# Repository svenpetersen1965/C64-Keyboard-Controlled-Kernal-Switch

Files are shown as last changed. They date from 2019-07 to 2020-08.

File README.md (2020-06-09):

# C64-Keyboard-Controlled-Kernal-Switch
This is a Kernal Switch for the Commodore C64, which does not requires any case modifications. The Kernal is selected by holing RESTORE and pushing a number key. 

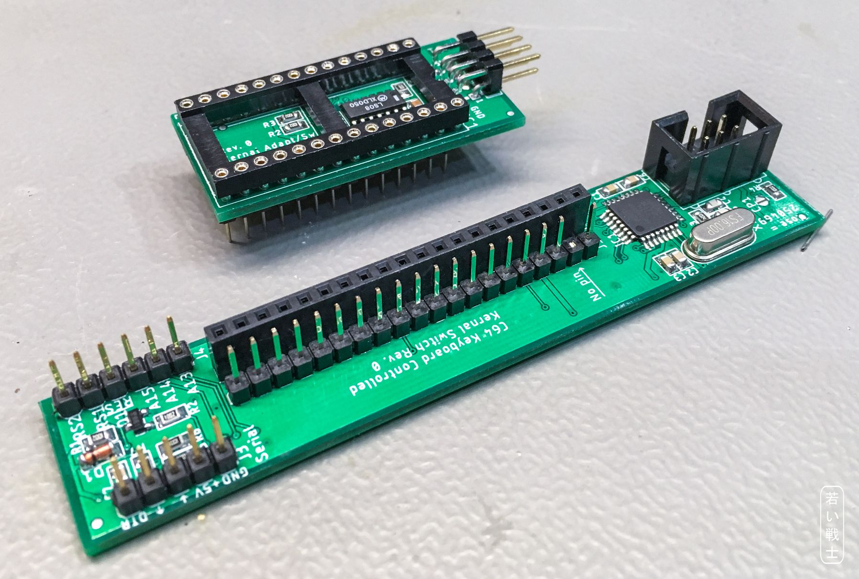
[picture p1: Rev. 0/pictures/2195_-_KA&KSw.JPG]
Kernal Switch and Kernal Adaptor


Jusrt holding RESTORE for several seconds will reset the C64. The index of selected Kernal is stored non-volatile, so the last selection will be executed after a power on.

Find some info on the required cable making <a href="http://tech.guitarsite.de/cable_making.html">on my website</a>

Watch the introduction on youtube: https://youtu.be/pfJxfMYcyzs

The Kernal Switch works in conjuctuion with a Kernal Adaptor:

https://github.com/svenpetersen1965/C64-Kernal-Adaptor-Switch-short-board- for ASSY 250469 Mainboards

https://github.com/svenpetersen1965/C64-Kernal-Adapter-Switch-Long-Board for all other Mainboards

I want to thank MindFlareRetro (https://www.youtube.com/channel/UCBbbiZC2YodIp2Pi-lywG-A/featured) for reviewing my documentation.

# Known Issue
Solved:

Some games/software require an EXROM-Reset, because they change the reset and/or NMI vector. Then the reset does not jump, where it should jump. It even seems, that the problem is persistent even after a power off. Don't panic... your C64 will function again, later. It seems, those games leave some traces in RAM, which have to get lost after being powered off for a while. 

This can be solved by also holding EXROM low while the reset. One of the two reserved IO pins in the pin header can serve to assert EXROM. The software will be changed and the result will be tested.

The problem stated above is some kind of copy protection and is described in detail here: http://tech.guitarsite.de/cbm80.html 

## Software Rev. 0.1
This software fixes the issue described above. An aditional connection is required. J4, Pin 5 (RS1) has to be connected to the EXROM signal (Expansion port, Pin 9, which can easily be accessed inside the C64) via a 220R resistor. The documentation has been updated.

## Software Rev. 0.2
This software makes use of the last free GPIO pin on J4 (Pin 6, "RS2" on Rev. 0 or "RESIO" on Rev. 1). A LED, that is connected there, will be on most of the time. When holding the RESTORE key and the time (about 3 seconds) is elapsed to initiate a "normal" reset, the LED switch off for a short time. Holding RESTORE for 5 seconds will initiate an EXROM reset. The LED signal should help to release the RESTOR key in time for a normal reset.

Board Rev. 1 already provides a current limiting resistor for an LED (R9). A value of 330R is suitable for a red, green or yellow LED, 50R is suitable for a blue LED.

Board Rev. 0 does not provide this resistor. Here, a resistor has to be installed in the LED cable. DO NOT try to connect an LED without a resistor!!! Theis can damage the LED and also the processor of the Kernal Switcher.  

# REV. 1
Revision 1 is released. The hardware Rev. 1 is tested ok. The documentation is finished.

# Calculation of the component prices
The BOM v1.1 was calculated. The total price of the components is 5.98€, which does not incluse any shiping fees. The cables were not calculated.

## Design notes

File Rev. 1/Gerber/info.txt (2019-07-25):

      
       Board: C64_Kernal_Switch (Keyboard controlled)
       Rev.:  1
  
       Files:
       ======
  
       All Gerber files are generated in extended gerber format (RS274X)
       *.TOP        : Film top copper
       *.BOT        :  -"- bottom copper
       *.STC        :  -"- top soldermask 
       *.STS        :  -"- bottom soldermask
       *.PLC        :  -"- silk screen top
       *.CRC        :  -"- cream top
       *.DK         : Drills plated Through (Excellon)
       *.NDK        : Drills not plated Through (Excellon)
       *.OUT        : Board outline

       Board Size:
       ===========
       Length     :   101.2 mm
       Width      :   20.0 mm
       Thickness  :   1.6 mm
       Material   :   FR 4
       Copper     :   35 um
       Surface    :   HASL
       
       Remarks:
       ========
       Width >= 6mil
       Distance >= 6mil
       Drill >= 0.35mm

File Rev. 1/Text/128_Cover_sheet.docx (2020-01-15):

Project Documentation

Commodore C64 – Keyboard Controlled Kernal Switch

Project number: 128

Revision: 1

Date: 25.07.2019


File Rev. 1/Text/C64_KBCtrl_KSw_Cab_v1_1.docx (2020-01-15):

C64 Keyboard Controlled Kernal Switch Rev. 1

Wiring v1.1

# Connections

There is one required connection, the Control Signals Cable. The Serial Cable to the USB/Serial-converter is optional and only required for uploading an Arduino sketch to the Kernal Switch.

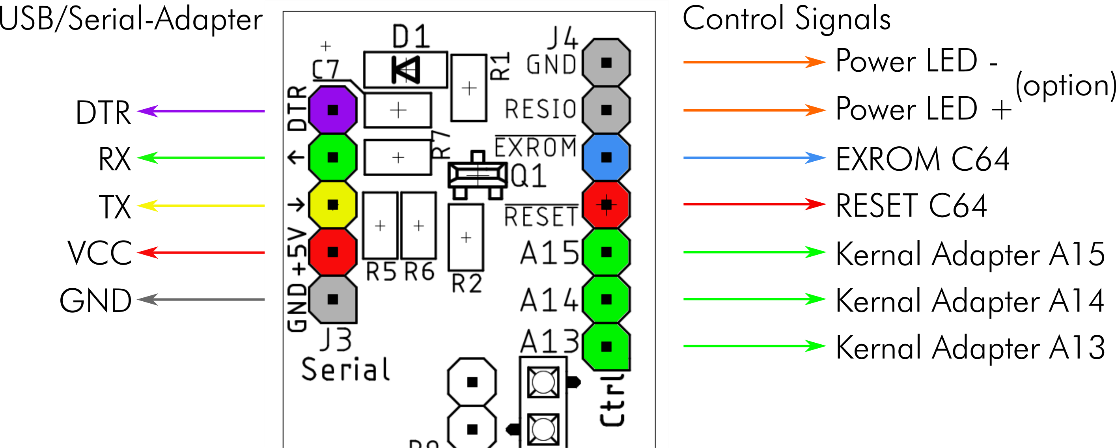
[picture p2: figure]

Figure 1: Connectors J3 and J4 of the Keyboard Controlled Kernal Switch

# Control Signal Cable

A wire connection between the keyboard controlled Kernal switch and the Kernal adapter is required to select the desired Kernal. Further on, the module has to reset the C64 after changing to that Kernal.

A recommended connector type is the wide spread Dupont connector. The contacts need to be crimped to the cable—this might be a challenge for some users.

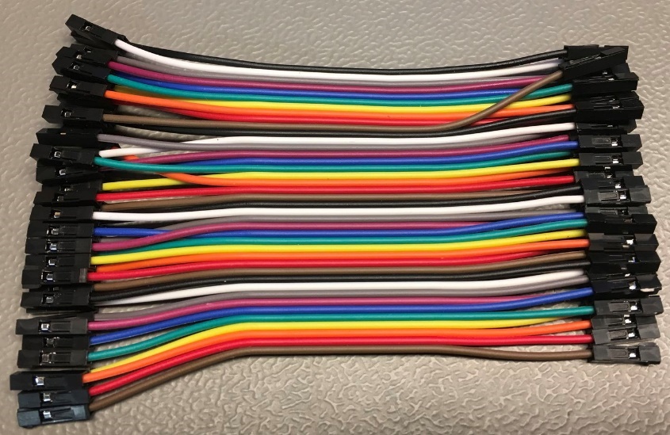
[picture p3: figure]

Figure 2: Prefabricated Dupont Cable

Alternatively, prefabricated Dupont cables (female–female) are readily available from eBay and are a suitable prefabricated solution. These prefabricated Dupont cables are usually sold as ribbon cables of up to 40 poles, each wire have an individual connector (Figure 2). The desired amount of wires can simply be peeled off of the ribbon cable. For the C64 short board, 30cm cables are required. For the C64 long board, 10cm cables are an adequate length. For the long board, the required cable for /EXROM is 30cm and for a short board it is 10cm long.

An alternative may be receptacles which fit on pin headers with the cables soldered to them. The next possible solution might be leaving the pin headers on Kernal switch and Kernal adapter not populated and solder in the cables directly. This is not really recommended.

A pin header (one pin) on the RESET signal of the C64 is required to be soldered. This RESET contact can be found near the user port. Looking from the port side, it is the 3rd contact from the left on the top side. Note, it is not good practice to solder the pin directly at the contact, but rather to a solder pad or via near it.

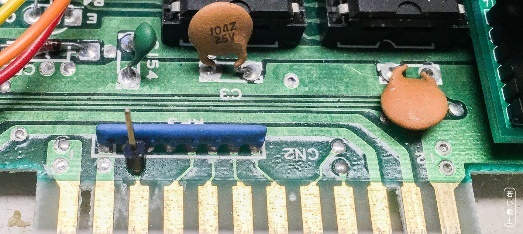
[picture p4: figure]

Figure 3: Reset Contact ASSY 250425 (identical to ASSY 250407) – Long Board

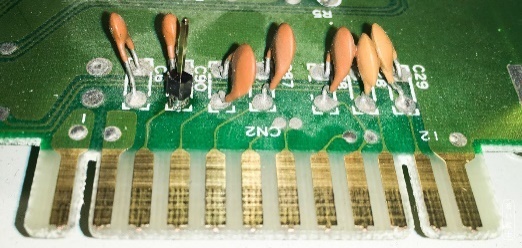
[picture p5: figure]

Figure 4: Reset Contact ASSY 250469 (front pin of C90) – Short Board

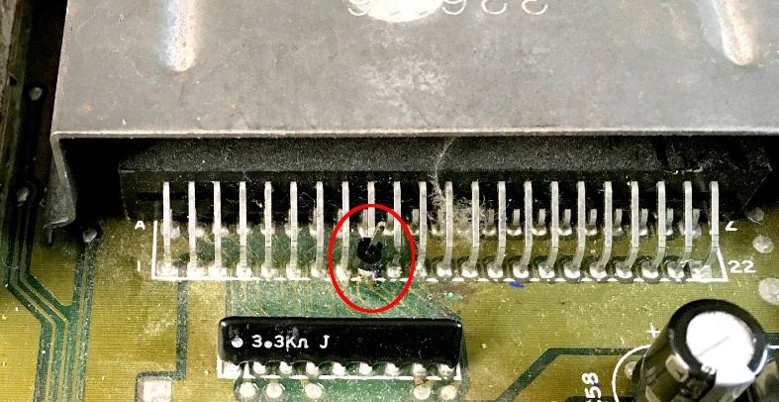
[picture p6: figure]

Figure 5: EXROM pin at the Expansion Port (Pin 9)

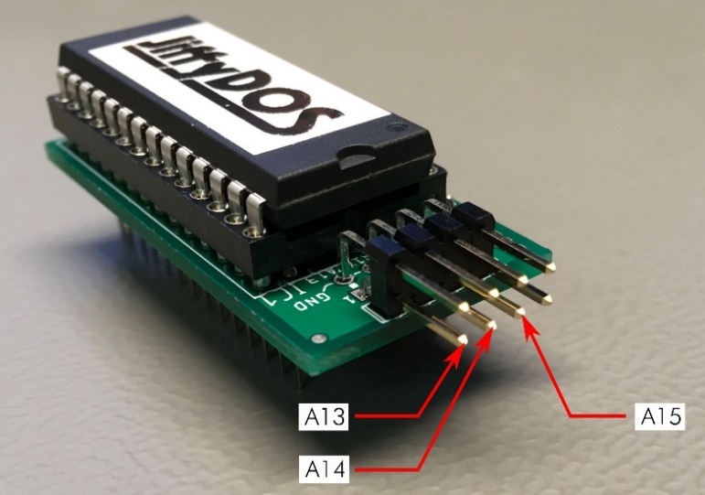
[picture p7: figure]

Figure 6: Connector of the Kernal Adapter

The required connections are:

Kernal Switch J4 | Kernal Adaptor JP1 | C64 Mainboard
A13 | A13 | -
A14 | A14 | -
A15 | A15 | -
| - | RESET Pin (Figure 3 & Figure 4)
| - | EXROM Pin (Figure 5)

Although the C64 long boards and C64 short boards require different Kernal adapters, both connectors are the same, as indicated in Figure 5.

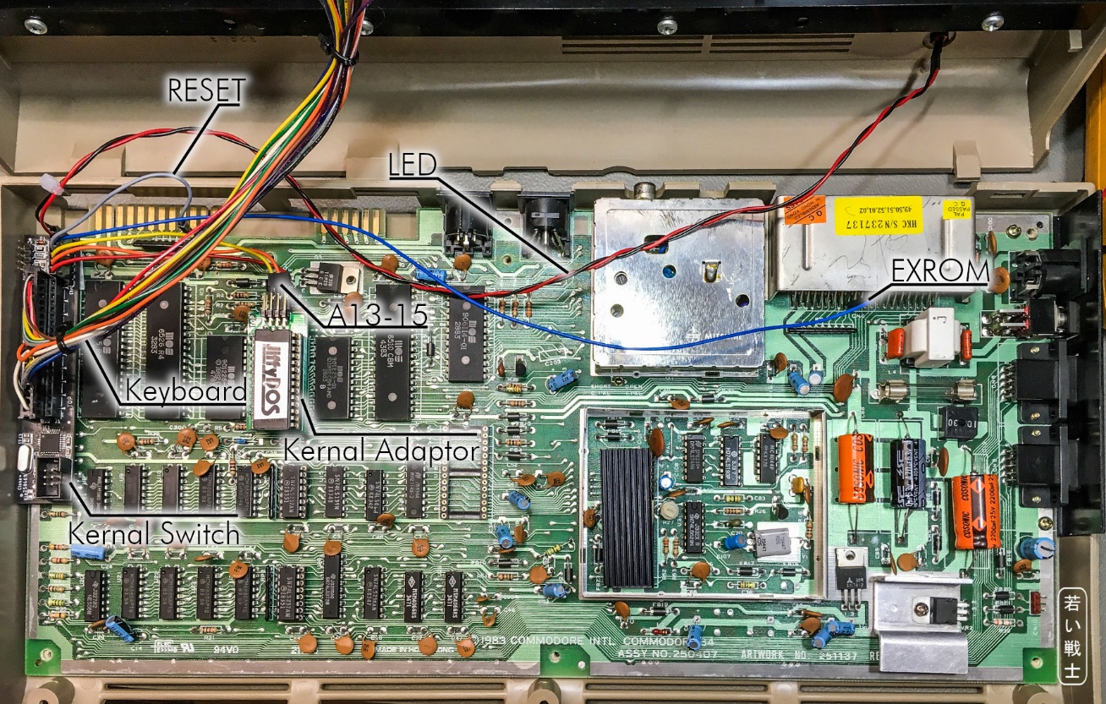
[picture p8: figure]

Figure 7: Wiring of ASSY 250407

Figure 7 shows the wiring of ASSY 250407 (ASSY 2502425 is similar). The grey cable is the reset signal, which is attached to the RESET pin header that was installed previously. The blue cable is EXROM.

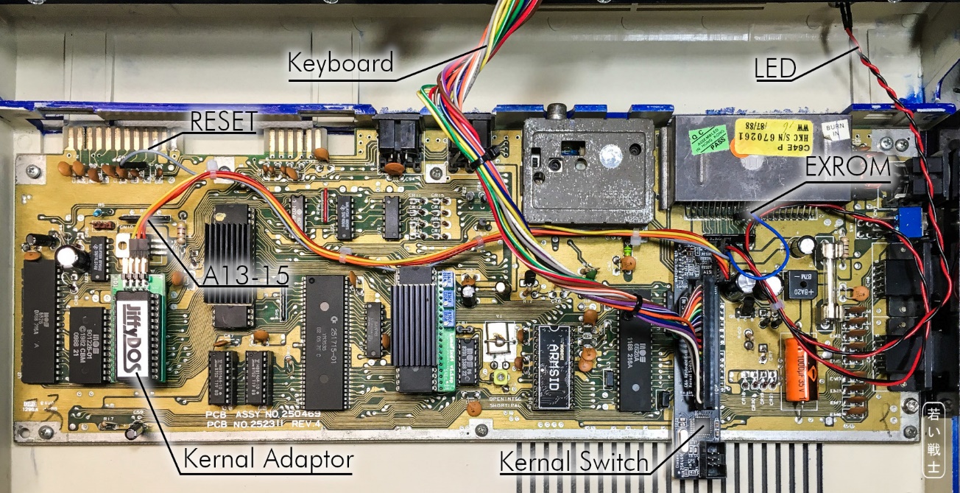
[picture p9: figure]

Figure 8: Wiring of ASSY 250469

Figure 8 shows the wiring of ASSY 250469 (short board). Again, the grey cable is the RESET signal, which is attached to the previously soldered RESET pin near the user port. The blue cable is EXROM.

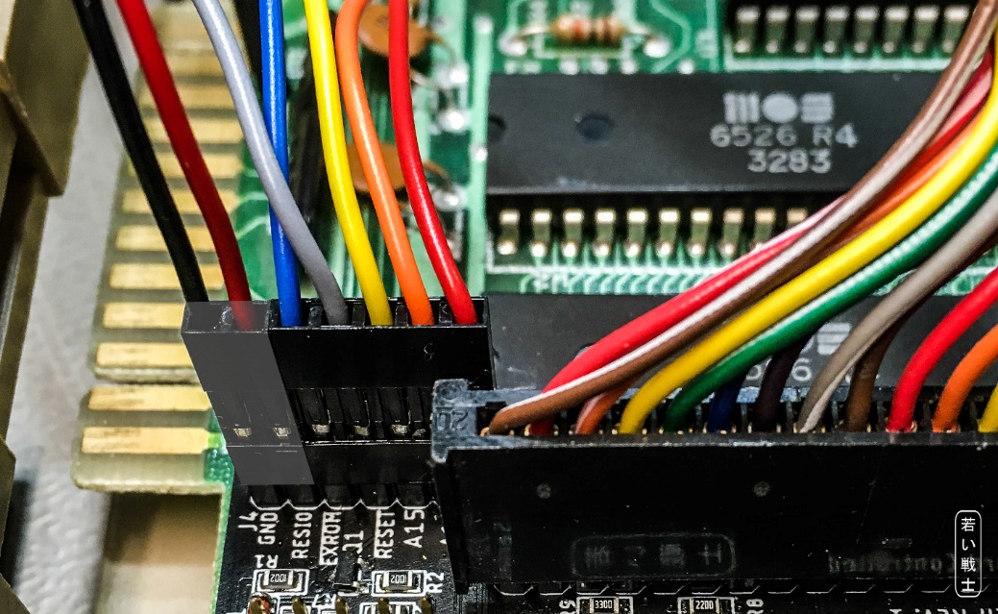
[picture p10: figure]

Figure 9: Wiring J4

For (the 7pin) J4, it is recommended to use a 2pin and a 5pin crimp housing/connector, in case the power LED is connected for signaling. This way, the top half of the C64 case can be easily separated from the bottom half with mainboard (disconnect LED and keyboard). Refer to Figure 9.

# Serial Cable

The Serial Cable can vary, depending on the used USB/Serial adapter board. An FT232 based adapter is recommended, which is widely used, provides +3.3V and 5V operation and driver software up to Windows 10.

The USB/Serial adaptor provides VCC (+5V) to the module. This is useful while programming the microcontroller but is not recommended if the module is inserted in the C64 and the computer is powered by it. In this case, the C64 would be powered via the USB interface of the computer. This will not damage the C64, however, for proper operation, the VCC should be interrupted or switched off. The serial interface can be helpful while debugging.

Again, the recommended connector type are Dupont connectors with the alternative of using receptacles, which also fit on standard pin headers. Direct soldering is not recommended.

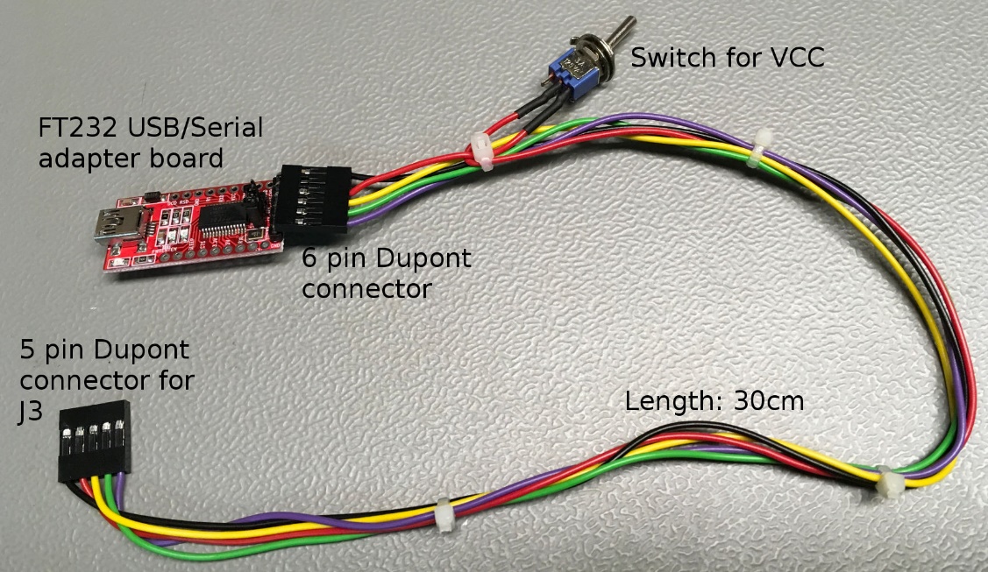
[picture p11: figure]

Figure 10: Serial Cable

Notice: During testing of the Kernal Switch, the C64 sometimes would not start. A ground loop was identified as the cause (mains → PC → USB → Adapter → Serial Cable → Kernal Switch → C64 → C64 Power Supply → mains). The power-on failure was resolved after interrupting the ground loop and the issue did not reoccur.

C64_KBCtrl_KSw_Cab_v1_1.docx 15.01.2020 10:02 Drafted by Sven Petersen Page 5 of 5 Doc.-No.: 128-6-04-01.1

C64_KBCtrl_KSw_Cab_v1_1.docx 15.01.2020 10:02 Drafted by Sven Petersen Page 1 of 1 Doc.-No.: 128-6-04-00

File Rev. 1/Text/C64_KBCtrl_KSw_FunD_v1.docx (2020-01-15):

C64 Keyboard Controlled Kernal Switch Rev. 1

Functional Description

This document applies to hardware version v1 with firmware version v0.1 or later.

IC1 is an ATmega328P processor and it provides the functionality of an Arduino Uno. X1 is the 16MHz quartz and forms the quartz oscillator together with C4, C5 and R3. J2 is the connector for in-system programming of IC1. It is required at least once for writing the Arduino bootloader.

A serial interface for debugging is provided on J3. This interface has a TTL-level serial signals. To connect it to a PC, a USB/serial converter board is required. Once the bootloader is programmed to IC1, the serial interface can serve to transfer a compiled Arduino sketch to the Kernal Switch. In case this serial interface is not required and J3, C7, D1and R7 can stay unpopulated.

The Kernal Switch has to distinguish between C64 long boards and C64 short boards; this because with a short board BASIC resides in the lowest 8k of the EPROM.

The address pins A[15..13] (of the EPROM) ranges from 001BIN to111BIN. With a long board all 8k memory slots can serve as a Kernal so A[15..13] range from 000BIN to 111BIN.

- CP1 serves for setting the board type: (i) to configure a long board leave CP1 open; (ii) to configure a short board CP1 must be closed by a simple solder bridge.
- The transistor Q1 serves for resetting the C64 and provides the required open collector output. A HIGH level on C64RES will pull the output LOW, which then resets the C64.
- J4 is the pin header, which provides the signals for selecting the Kernal (KSW_A13 .. KSW_A15), for resetting the C64 (), the signal and one GPIO pin (RESIO) which is utilized to drive a power LED (firmware v0.2). The GND pin (in conjunction with the RESIO) might be used for connection an LED.
- R8 will limit the current on , in case a cartridge holds this signals HIGH. It is calculated to provide a stable LOW level voltage together with the 3.9kΩ pull-up resistor (network) on the C64 mainboard. A value of 300Ω might also work, but is not tested.
- R9 can be used as a bias resistor for an LED. 330Ω is a suitable value for a red or green LED.
- J1 is a bottom entry receptacle, the pins of the keyboard connector are inserted through holes in the PCB into this connector from below. All keyboard signals are connected here. J1 provides the supply voltage (+5V) for the circuit on the Kernal switch.
- J5 is the pin header for connecting the keyboard. All (keyboard) signals from J1 are connected to the same pin on J5.
- Only the required scan signals are connected to IC1. That is column 1, 2, 3, 4 and 7, as well as row 0 and 3. The row signals are pulled LOW in case a key in the row is being pressed. These row signals are connected to the two external interrupt pins (INT0 and INT1) of IC1. The key scan signals have to be configured as “input with weak pull-up resistor”, since the TTL logic of the C64 interprets an open input as a HIGH input, while it is an illegal state for the MOS logic of IC1.

C64_KBCtrl_KSw_FunD_v1.docx 13.01.2020 16:34 Drafted by Sven Petersen Page 2 of 2 Doc.-No.: 000-6-00-00

C64_KBCtrl_KSw_FunD_v1.docx 13.01.2020 16:34 Drafted by Sven Petersen Page 1 of 1 Doc.-No.: 128-6-02-01

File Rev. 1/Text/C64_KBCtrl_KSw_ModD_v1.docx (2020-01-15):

C64 Keyboard Controlled Kernal Switch Rev. 1

Module Description

# Introduction

The C64 Keyboard Controlled Kernal Switch is a module that passively watches the scan activity of the C64 keyboard and is capable of setting the higher address bits for Kernal adaptors, similar to project number 123 C64 Kernal-Adaptor/Switch for Short Boards that can address up to 7 Kernals, project number 124 C64 Kernal-Adaptor/Switch for Long Boards that can address up to 8 Kernals and/or the Character Set Adaptor project number 126 C64 CHARSET-Adaptor/Switch that can address 16 character sets.

A signal is provided to reset the C64 while/after selecting the Kernal via the three most significant EPROM address bits. Two other GPIO-pins (and RESIO) of the processor Atmel ATmega328p are routed to the pin header J4. Firmware v0.2 uses RESIO for driving a signaling “Power” LED.

The ATmega328p can be configured with an Arduino Uno. A pin header provides access to the serial interface for uploading the compiled Arduino sketches. Initial programming is performed via the ICSP connector J2.

The board fits between the keyboard connector of the C64 mainboard and the keyboard itself. All keyboard signals are interconnected and some keyboard signals are monitored by the micro controller.

Watch a brief overview video: http://bit.ly/C64KbKernalSwitch-Intro

# Usage of the Kernal Switch

To make use of the Kernal Switch, more than one Kernal should be programmed to the EPROM on the EPROM adaptor. The Kernal can be selected by pressing RESTORE and a number key simultaneously. The Kernal, determined by the number will be selected and the C64 will be reset. This selection is non-volatile and will be effective even after switching off the C64.

Holding down the RESTORE key for about 2-3 seconds and then releasing it (without pressing a number), a reset of the C64 is performed. In case the Power LED is connected to the Kernal Switch as well, this LED will switch off for a short time, after the time for a normal RESET is elapsed (software v0.2 or later). Holding down the RESTORE key for longer (about 4 seconds), the “unstoppable” EXROM reset will be performed (software v0.1 or later).

In case an empty Kernal memory slot is selected, the C64 will crash, since there is no Kernal found. In this case, the C64 does not perform a keyboard scan and since the Kernal Switch is only listening to the keyboard scanning, but does not perform any keyboard scan, the Kernal number could not be set manually anymore. After several seconds without keyboard scan, the Kernal switch will automatically recover to the first Kernal and reset the C64. This will recover the system.

Some cartridges will not perform a keyboard scan as well (such as the Dead Test cartridge). The recovery mechanism will conflict with this kind of cartridge and reset the C64 after several seconds. To circumvent this problem, it is possible to deactivate the Kernal switch by pressing RESTORE 0 (zero). This will switch to the first Kernal and set a non-volatile flag. After switching off the C64 and inserting the cartridge, no keyboard activity timeout will be performed, the cartridge will work normally.

After the cartridge was removed, the first Kernal will be executed and (of course) a normal keyboard scan will be performed. Selecting a Kernal with RESTORE and a number will activate the Kernal Switch again and the new selection will be effective.

Keys | Action
RESTORE (hold >1.5sec, <3sec) | Normal Reset
RESTORE (hold > 3sec) | EXROM Reset
RESTORE <1>…<7> | Short board: Select Kernal number 1…7
RESTORE <1>…<8> | Long board: Select Kernal number 1…8
RESTORE <0> | Select save Kernal (the first), switch off keyboard scan time out (for cartridges)

<0>: 0 key (zero)

<1>: 1 key

…

<8>: 8 key

# The Unstoppable (EXROM) Reset

This sort of reset will also assert the -Signal (which has to be connected to J4, Pin 5). The background for this is a trick, that some software (e.g. Gyruss, PAC-MAN or Poltergeist) tries to prevent a normal reset of the C64 as kind of a copy/hacking protection. A (fake) cartridge signature is written to the RAM at address $8000 (HEX) and the following bytes. This consists of the cold start vector, the NMI redirection vector and a “CBM80” signature in RAM. On a normal reset, the Kernal finds this signature in RAM and redirect the vectors, mentioned before. This way, after playing these games, the RESET does not work well and other games cannot be loaded. With the EXROM reset, a normal boot can be accomplished. Nevertheless, the signature stays in RAM (even a couple of seconds without power!!!). The next reset will still get redirected by this fake cartridge signature.

The destruction of the signature is required and can be accomplished by the instruction

POKE32772,0

and another (normal or EXROM) reset. This POKE changes the C of CBM80, on boot up, this signature is not found and the cold start and NMI vectors are not modified. The C64 is working again.

It was observed, that the fake signature stays intact even after several seconds (maximum time was >1 minute) of power off. The C64 might boot up to a black screen or even shows parts of the previous game. This has created some spooky experience after playing Poltergeist. An EXROM reset and the procedure described before will fix this problem. Also switching off the C64 for a minute or longer will help.

Some cartridges hold the EXROM signal HIGH. In this case, the EXROM reset might not work. To prevent a short circuit, the 220Ω resistor mentioned before is inserted into the signal on board.

The Final Cartridge III (+) does not work with the EXROM reset. It has an excellent reset switch, anyways.

# Assembly

It is assumed, that the person who assembles the Kernal Switch is experienced in soldering. First the SMD parts should be soldered, the bottom entry receptacle J1 should be soldered last can be aligned to the holes in the board using the pin header J5. Pin2 of J2 has to be clipped (refer to Figure 1) and the connector has to be inserted into the holes from the solder side. Then J1 has to be placed over those pins and the connector has to be aligned in a way that it is centered on the J1 silk screen drawing and the SMD pins are in the middle of the solder pads (refer to Figure 2). Then one pin has to be soldered. Then the connector might need to be corrected and a second pin can be soldered. If the pin header inserts easily from the bottom, all other pins can be soldered.

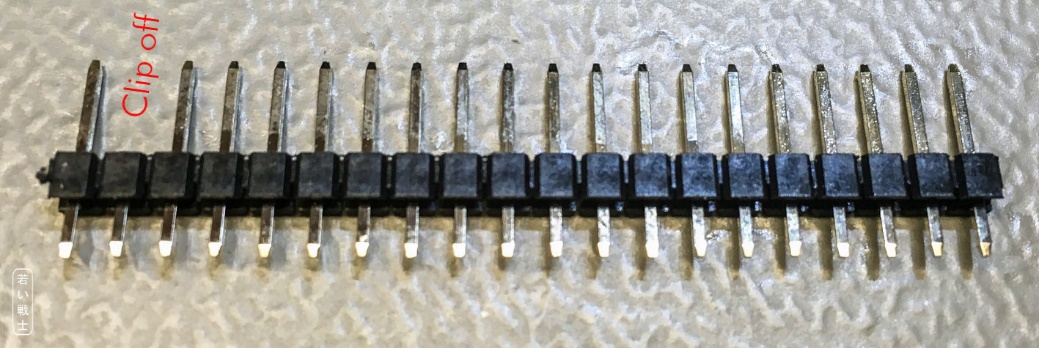
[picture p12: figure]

Figure 1: Preparation of J5 (clipping off the 2nd pin)

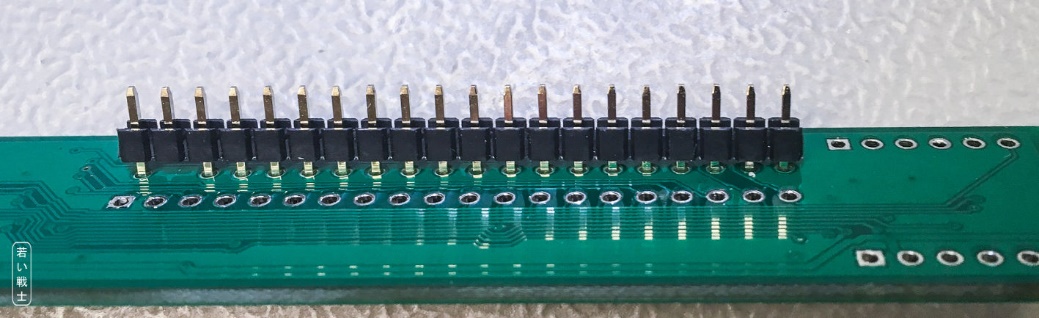
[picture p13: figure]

Figure 2: Centering of J1

Finally, the through-hole parts have to be soldered.

Close (or leave open) the solder bridge CP1, depending whether a short board (ASSY 250469, close CP1) or a long board (all other ASSY numbers, leave CP1 open) is present in the C64.

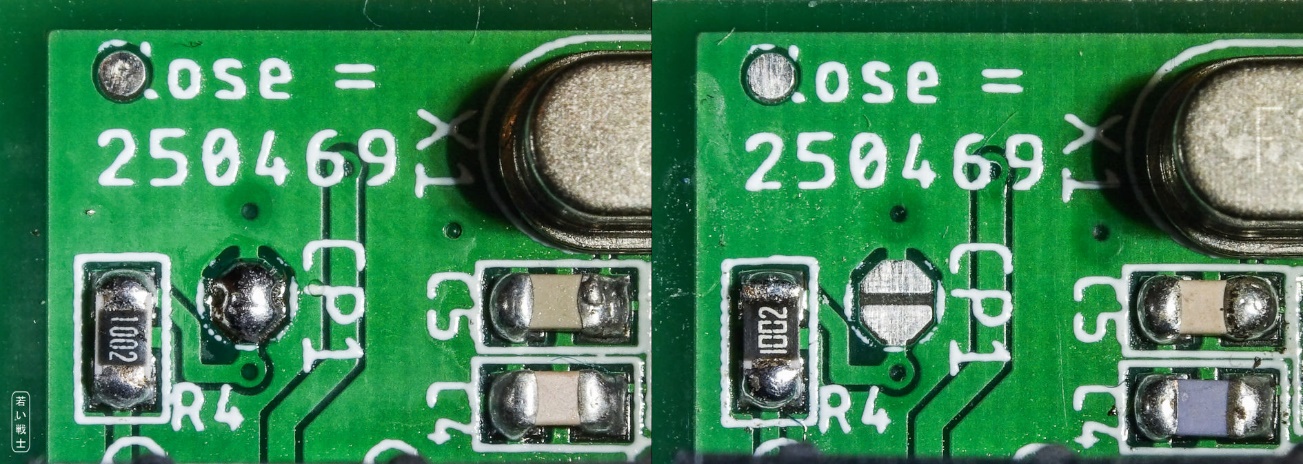
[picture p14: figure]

Figure 3: CP1 configured for short board (left) and long board (right)

To prevent the components of the Kernal Switch from making contact with any parts of the C64 mainboards, the area top and bottom of the keyboard connectors can be taped with duct or gaffer tape.

After being completely assembled, the micro controller IC1 (ATmega238P) has to be programmed. Refer to document number 128-6-05-00 (Programming Guide).

For wiring the Kernal Adaptor, the Kernal Switch and the C64, refer to document number 128-6-04-01 (Wiring).

The Assembly of the Kernal Adaptor might require de-soldering the Kernal ROM U4 and installing a socket.

# Troubleshooting

In case the C64 does not start properly, make sure that the Kernal Adaptor is inserted properly into the socket and the EPROM is properly programmed. At least the first Kernal has to be programmed. The Kernal Switch should sit firmly on the keyboard connector and does not make electrical contact with any component leads of the C64 mainboard.

The Atmega328P has to be programmed with either the production file or the *.hex and the fuses have to be set properly (refer to document 128-6-05-01: Programming Guide).

Also, it is important to open or close the configuration solder bridge CP1 on the module to determine between a short and a long board. For C64 short boards, the solder bridge has to be closed, the BASIC has to be in the first 8k of the EPROM and a Kernal (original recommended) has to be in the 2nd 8k of the EPROM.

In case an EPROM smaller than a 27C512 is used, do not connect the unused address bits. On a 27C256, A15 has to be high/open, on a 27C128, A15 and A14 have to be open. A27C64 is not recommended. Refer to the documentation of the used Kernal Adapter.

In case the Kernals do not switch in the sequence as they were programmed into the EPROM, most likely, the wiring between the Kernal Switch and the Kernal Adapter is wrong (refer to document 128-6-04-01: Wiring) or the contacts are not clean or bad in some way. Clean the contacts and reseat the connectors.

Check, if the RESET pin is really connected to RESET of the C64. Again, check the cable to the RESET pin.

In case it is not working at all, remove the cable between the Kernal Switch and the Kernal Adaptor and set jumpers. Set all three jumpers (A13, A14, A15) for a long board and the jumpers A14 and A15 for a short board. In case it is working now, the Kernal Switch is selecting the wrong Kernal (maybe an empty 8k slot). Again, check the cable, measuring the pins A13, A14 and A15 on the J4 with a multimeter. Keep in mind that the first Kernal for a short board is 001BIN and for a long board it is 000BIN. A 0 here is represented by a low voltage (<0.7V) and a 1 is represented by a HIGH voltage (>4V).

If the problem is not solved, checking the solder joints is required. To see, if the software is running on the micro controller, a Serial Cable and a USB/Serial Adaptor plus the Arduino software (Tools → Serial Monitor, set to 9600 baud) might help.

After power up, the software should send messages via the serial cable. The RESTORE key has to be detected and reported (after holding it down) and a number key will be reported too.

Make sure, that the C64 power supply and the PC are connected and that the cables do not form a big loop (ground loop), as this might prevent proper function. The serial connection is only for programming (in some cases) and for debugging, so it is not a problem if a ground loop causes problems. It was experienced during testing, that with a big ground loop (a couple of square meters) the C64 did not always start properly.

# Keyboard Monitoring

The columns 1-4 and 7 as well as the rows 0 and 3 are connected to GPIO-pins of the micro controller. The C64 sends a scan bit to the columns, which are HIGH on default. The scan bit is LOW and it is shifted through the columns, one at a time. The rows are read back by the C64. A LOW signal on one or more row bits indicates a pressed key.

The following keyboard scan information can be obtained by the microcontroller:

| Column
| 7 | 4 | 3 | 2 | 1
Row 0 | “1” | “9” | “7” | “5” | “3”
Row 3 | “2” | “0” | “8” | “6” | “4”

It is obvious that only the numerals are being monitored. Further the RESTORE key is connected to the microcontroller.

# Programming Model

Pin | GPIO | Arduino | Function | Configuration
30 | PD0 | D0 | RxD | Input | Serial Receive
31 | PD1 | D1 | TxD | Output | Serial Transmit
32 | PD2 | D2 | Row0 | Input, weak pull-up | Active LOW, INT0
1 | PD3 | D3 | Row3 | Input, weak pull-up | Active LOW, INT1
2 | PD4 | D4 | KSW_A13 | Output | Kernal Switch A13
9 | PD5 | D5 | KSW_A14 | Output | Kernal Switch A14
10 | PD6 | D6 | KSW_A15 | Output | Kernal Switch A15
11 | PD7 | D7 | C64RES | Output | Active HIGH
23 | PC0 | A0 | COL1 | Input, weak pull-up | Keyboard column 1
24 | PC1 | A1 | COL2 | Input, weak pull-up | Keyboard column 2
25 | PC2 | A2 | COL3 | Input, weak pull-up | Keyboard column 3
26 | PC3 | A3 | COL4 | Input, weak pull-up | Keyboard column 4
27 | PC4 | A4 | COL7 | Input, weak pull-up | Keyboard column 7
28 | PC5 | A5 | | Input, weak pull-up | RESTORE-Key, active LOW
12 | PB0 | D8 | | Input | Short Board, active LOW
13 | PB1 | D9 | | output | C64 (a resistor R8 is in series with this signal)
14 | PB2 | D10 | RESIO | TBD | Reserve IO Pin (a resistor R9 is in series with this signal)

# Connectors

## J1 - Keyboard connector to mainboard

Bottom Entry receptacle (1x20p, pitch 2.54mm) – Harwin M20-7862042

Pin | Signal | Pin | Signal
1 | GND | 11 | ROW1 (PB1)
2 | No pin | 12 | ROW0 (PB0)
3 | | 13 | COL0 (PA0)
4 | +5V | 14 | COL6 (PA6)
5 | ROW3 (PB3) | 15 | COL5 (PA5)
6 | ROW6 (PB6) | 16 | COL4 (PA4)
7 | ROW5 (PB5) | 17 | COL3 (PA3)
8 | ROW4 (PB4) | 18 | COL2 (PA2)
9 | ROW7 (PB7) | 19 | COL1 (PA1)
10 | ROW2 (PB2) | 20 | COL7 (PA7)

## J2 – In System Programming

2x3 box pin header (2.54mm pitch). This connector is used for the initial in-system programming of the ATmega238p (IC1). 89

Pin | Signal | Pin | Signal
1 | MISO | 2 | +5V
3 | SCK | 4 | MOSI
5 | (IC1) | 6 | GND

## J3 – Serial/Debug

1x5 pin header (2.54mm pitch). In Arduino mode (after programming the Arduino boot loader), a USB/serial converter can be used to transfer the compiled Arduino sketches and for debugging with the serial monitor.

Pin | Signal | USB/Serial converter
1 | GND | GND
2 | +5V | +5V
3 | TxD (output) | RX
4 | RxD (input) | TX
5 | DTR (input) | DTR

## J4 – IO-Connector

1x7 pin header (2.54mm pitch)

This connector outputs the control signals of this board. It is for being connected to the Kernal and/or keyboard adapter. It also provides one reserved IO-Pin for later use. The GND might be useful, in case the RESIO-Pin is used to drive an LED (the power LED)?

Pin | Signal | Function
1 | KSW_A13 | Kernal Switch/Adapter A13
2 | KSW_A14 | Kernal Switch/Adapter A14
3 | KSW_A15 | Kernal Switch/Adapter A15
4 | | RESET signal for the C64 (to be connected to a RESET point on the mainboard)
5 | | signal for the C64 (to be connected to an EXROM point on the mainboard)
6 | RESIO | Reserved IO
7 | GND | GND pin for multi-purpose use

## J5 - Keyboard connector

Pin header (1x20p, pitch 2.54mm) – Pin 2 clipped off (no pin)

Pin | Signal | Pin | Signal
1 | GND | 11 | ROW1
2 | No pin | 12 | ROW0
3 | | 13 | COL0
4 | +5V | 14 | COL6
5 | ROW3 | 15 | COL5
6 | ROW6 | 16 | COL4
7 | ROW5 | 17 | COL3
8 | ROW4 | 18 | COL2
9 | ROW7 | 19 | COL1
10 | ROW2 | 20 | COL7

# Documents

Document | Document Number
Disclaimer | -
Module Description (this document) | 128-6-01-**
Schematic | 128-1-01-**
PCB prints | 128-2-01-**
Functional Description | 128-6-02-**
Software Description | 128-6-03-**
Wiring | 128-6-04-**
Programming Guide | 128-6-05-**
Testing | 128-6-06-**
Bill of Material | 128-5-01-**.*

** depends on revision

# Revision History

## Rev. 0

- Prototype (fully functional)

## Rev. 0 → Rev. 1

- J4, pin 5 is now for (software v0.1 or later required)
- J4 has an additional GND Pin (useful in case RESIO is connected to an LED)
- Series resistor in and RESIO signal (R8, R9: 220Ω or whatever is required).
- Additional 1KΩ (R10) between GND and +5V for faster discharge

C64_KBCtrl_KSw_ModD_v1.docx 14.01.2020 09:49 Drafted by Sven Petersen Page 7 of 7 Doc.-No.: 128-6-01-01

C64_KBCtrl_KSw_ModD_v1.docx 14.01.2020 09:49 Drafted by Sven Petersen Page 1 of 1 Doc.-No.: 128-6-01-01

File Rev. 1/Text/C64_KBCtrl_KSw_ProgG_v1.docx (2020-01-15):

C64 Keyboard Controlled Kernal Switch Rev. 1

Programming Guide

# Introduction

The microcontroller on the Kernal switch has to be programmed to function properly. There are several ways of transferring the program into IC1.

Since the program is based on the Arduino IDE, the program can be considered to consist of three parts:

- the Arduino Bootloader (optiboot_atmega328.hex)
- the fuses
- the compiled sketch (c64kbksw.ino)

The bootloader will enable the Arduino IDE to transfer (compiled) sketches via the serial cable into the ATmega328P microcontroller on the Kernal switch.

The fuses are the configuration of the ATmega328P. If those are not set properly, the Kernal switch will not work like desired.

The sketch is the source code of the program. It needs to be compiled and uploaded by the Arduino IDE (=Integrated Development Environment).

# One Pass Programming

It is possible to transfer the bootloader, the compiled sketch and the fuses in one pass. That requires a suitable programmer (like the Atmel ICE, an SDK500 based programmer or another supported programming hardware). Further on, the Atmel Studio software is required. It is the IDE for writing software for Atmel controllers and programming the chips.

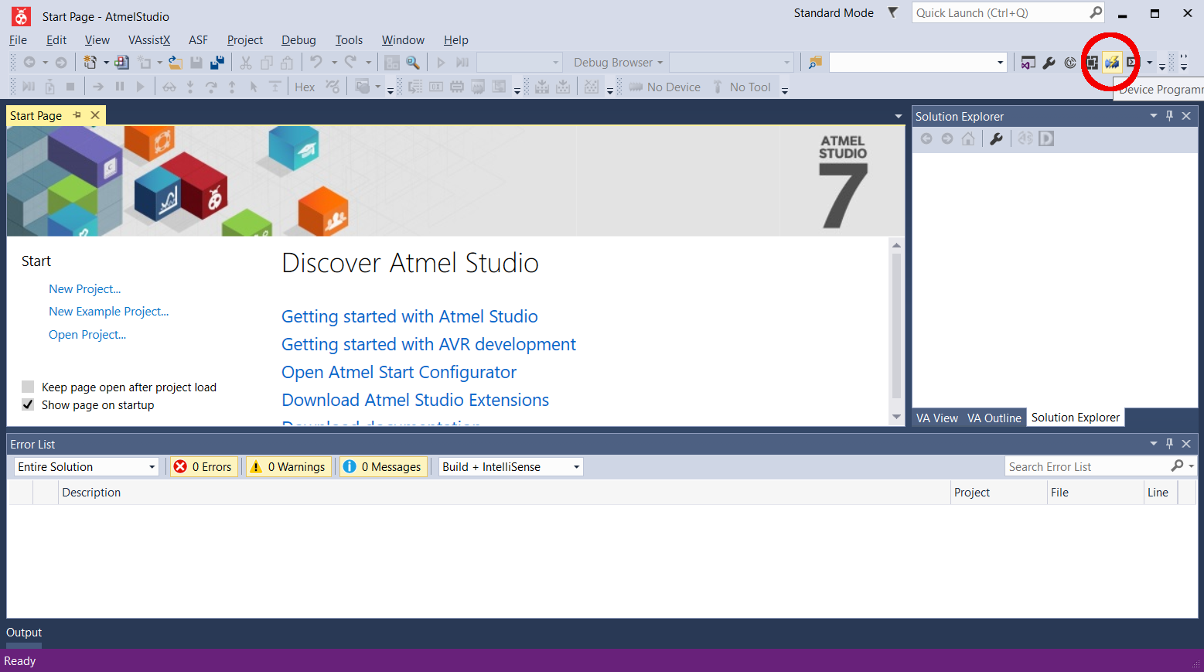
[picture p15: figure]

Figure 1: Atmel Studio IDE

The programming data is c64kbksw_v0_0.elf (or a later version). It was read out from an already programmed Kernal switch with a programmer and stored.

## Step 1

Start the Atmel Studio IDE and select the Device Programming Tool as shown in Figure 1.

## Step 2

Configure the tool (=the programmer), the device (ATmega328P), the interface (ISP = in-system programming) and click “Apply”, like in Figure 2.

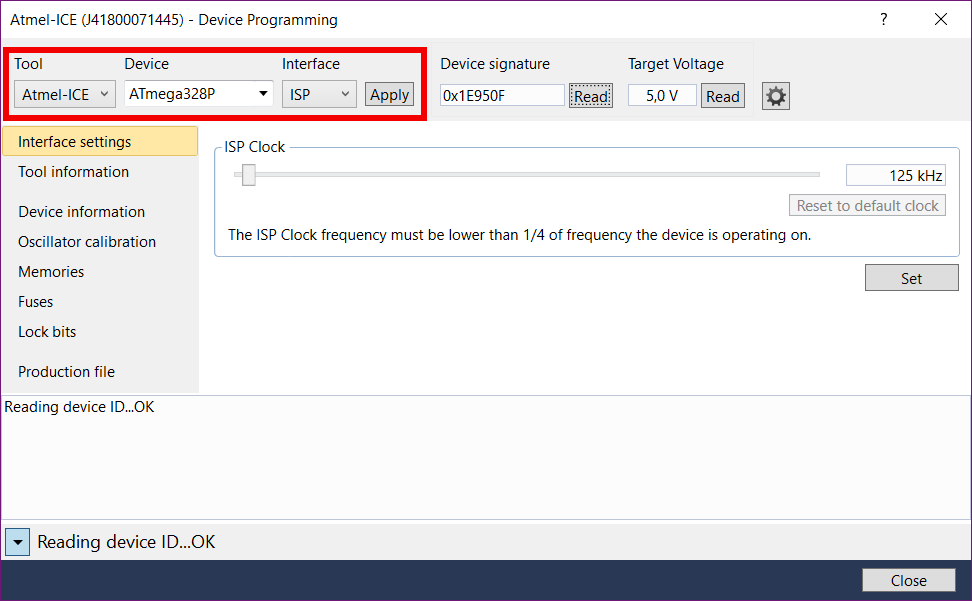
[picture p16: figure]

Figure 2: Device Programming

When you click “Read”, the Device signature should be displayed and the Target Voltage should be shown (about 5V). In case, it does not, the module needs to be powered externally with 5V (connector J3). It can be done with the USB/Serial adaptor and the serial cable, or just a bench power supply.

## Step 3

Click “Production File”, then select the ELF production file (c64kbksw_v0_0.elf or later version) from the location, where you have stored it. Check “Flash” and “Fuses”, also “Erase memory before programming” and “verify programmed content”, like shown in Figure 3.

Now, click the “Program” button. The programming will start.

While the programming, the status is reported in the lower part of the window. This is marked yellow in Figure 4. Erasing, programming Flash and Verifying, Programming Fuses and Verifying should all be reported “OK”.

Now, the program (bootloader and fuses included) is completely transferred to the ATmega328P. The module should be fully functional now. Since it contains the bootloader, the Kernal switch can be modified with the Arduino IDE and a serial cable.

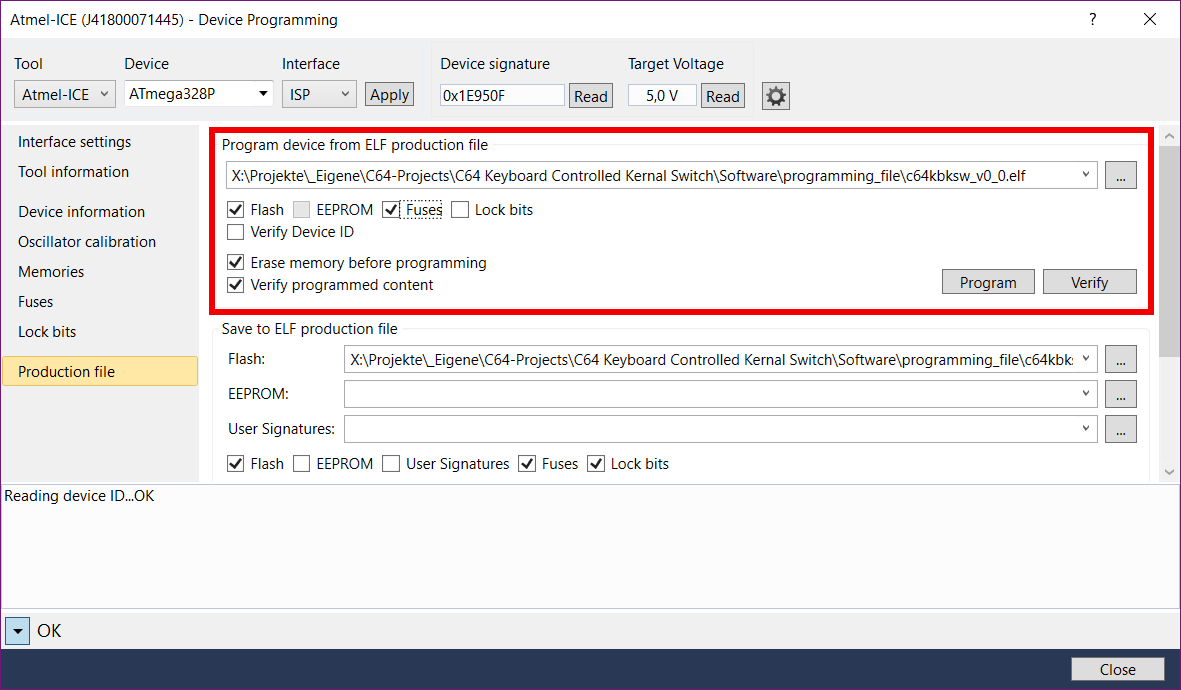
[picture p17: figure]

Figure 3: Production File settings

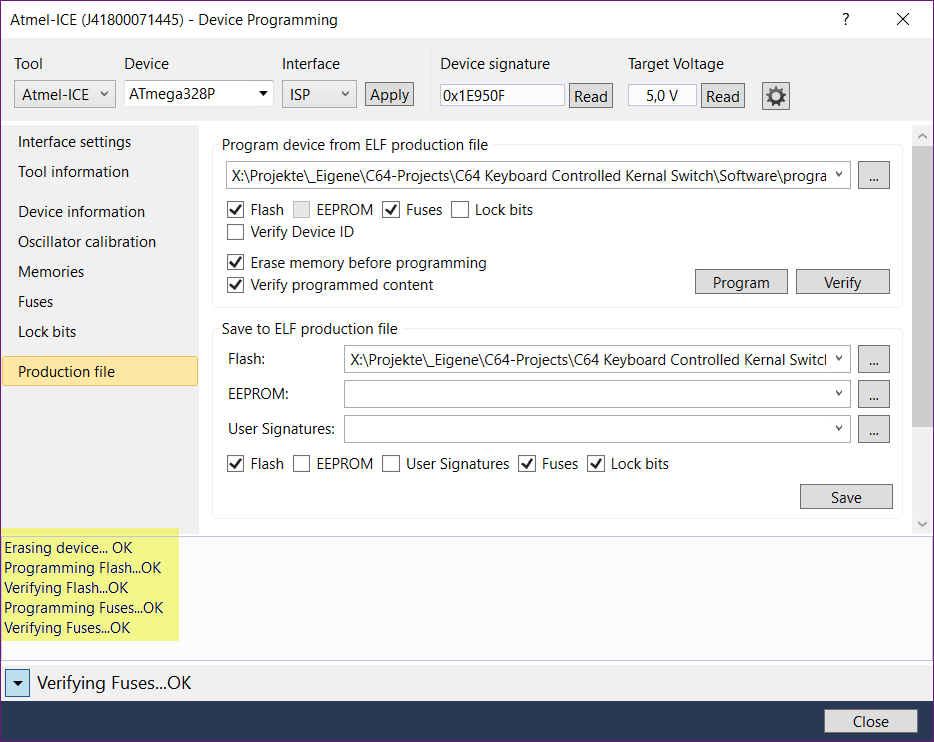
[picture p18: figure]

Figure 4: Programming the device

The fuses of the ATmega328P should be set like this:

- EXTENDED: 0xFD
- HIGH: 0xDE
- LOW: 0xFF

This can be checked with the Device Programming tool like in Figure 5.

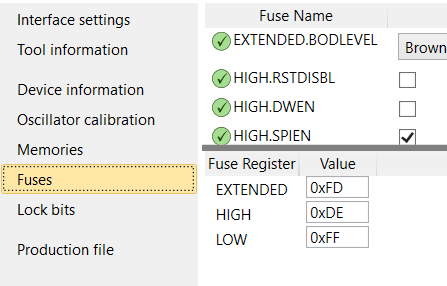
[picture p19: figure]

Figure 5: Fuses

# One Pass Programming TL866

The ATmega328P can be programmed either with a TQFP32 adaptor or via the ICSP port. In both cases, the program (c64kbksw_v0_0.hex or a later version) has to loaded to the programming buffer (the format is Intel HEX) and the fuses have to be set manually (see Figure 6). The file contains the bootloader and the compiled sketch. No further programming is required.

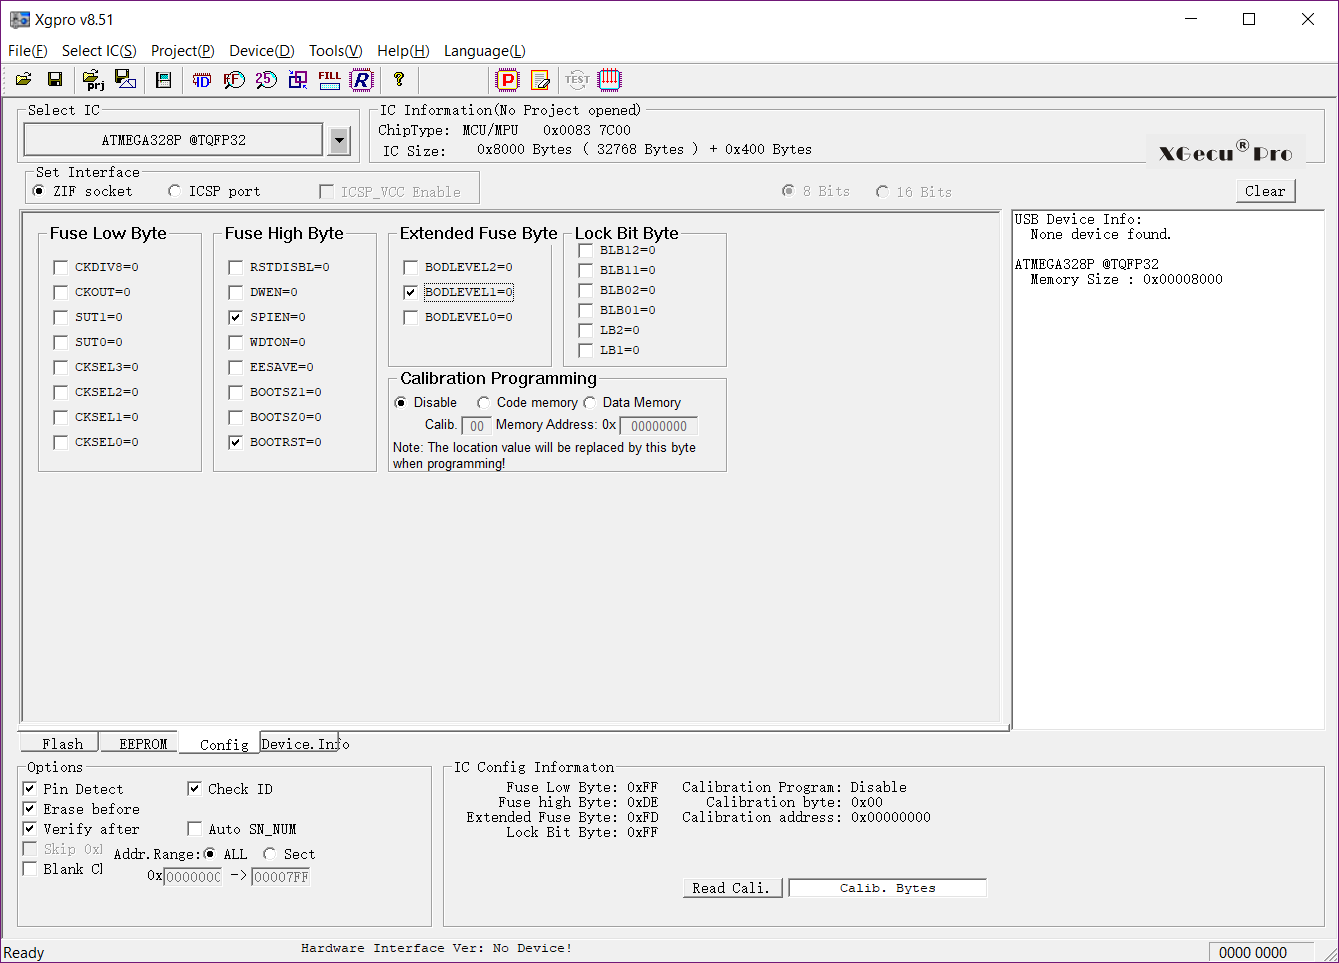
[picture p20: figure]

Figure 6: Correct setting of the fuses

This setting can be found in the “Config” tab.

Without a TQFP32 adaptor, the processor can be programmed in-system. The TL866II+ and the TL866A provide such an ICSP port. As a cable, a 6-wire Dupont cable will work (see Figure 9).

The connections should be made according to Figure 8.

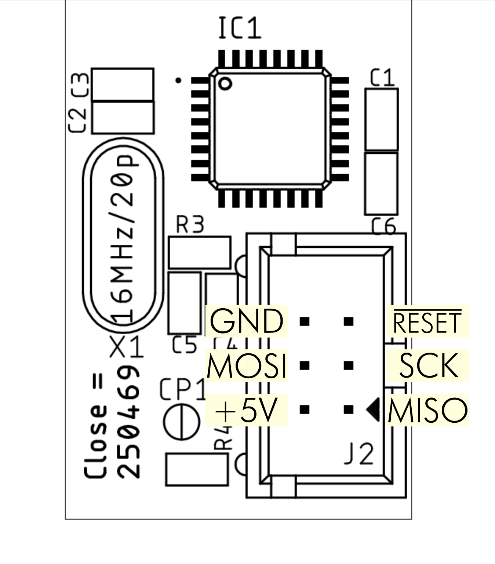
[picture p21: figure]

Figure 7: Pinout of the ICSP connector J2

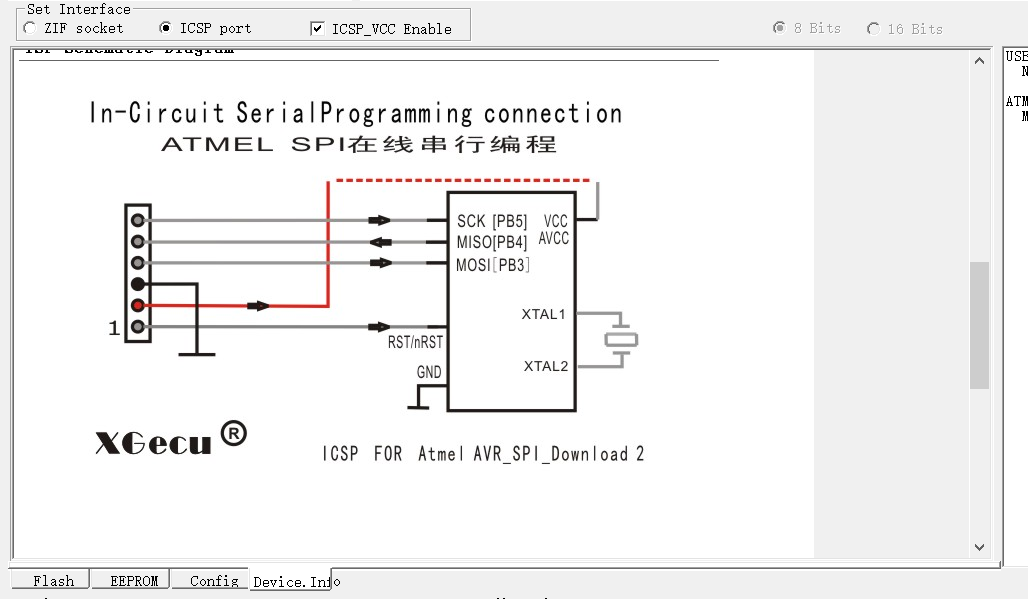
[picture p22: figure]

Figure 8: ICSP connection from TL866II+ to ATmega328P

The Dupont cable needs to be connected correctly, the connection has to be double checked to prevent harming the module or the programmer. In case, the repeated programming is intended, it might make sense to build a cable with a real 6x1 and 3x2 pin Dupont crimp housing (the 1pin crimp housings of the cable can be uninstalled).

When programming the controller, make sure, the code memory and the fuses are checked (Figure 10).

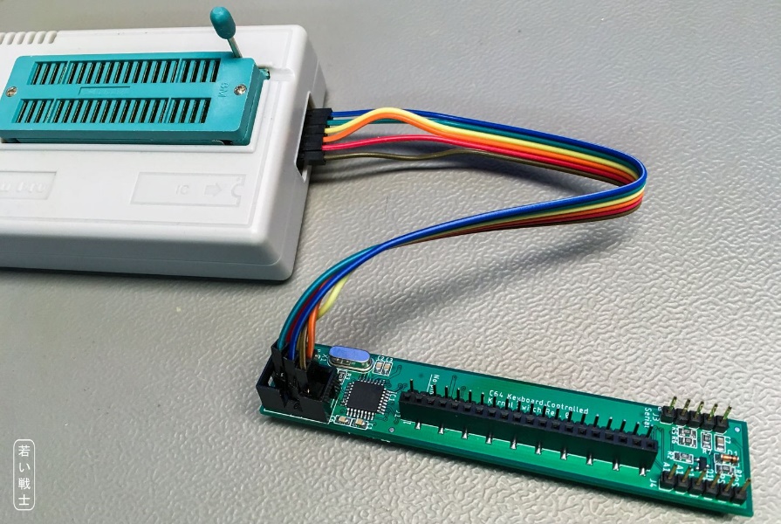
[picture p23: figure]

Figure 9: ICSP with a Dupont cable

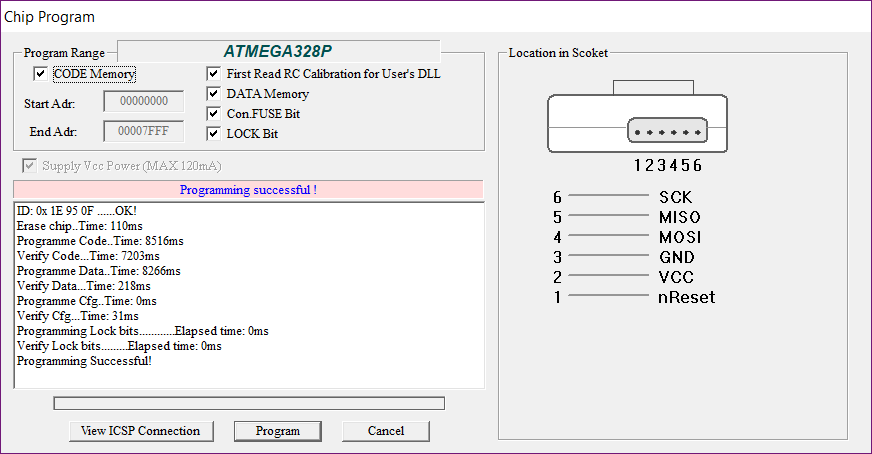
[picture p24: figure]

Figure 10: Programming the ATmega328P with the TL866II+

# Programming the bootloader from the Arduino IDE

With a supported programmer or a programmer made from an Arduino Uno, the Arduino bootloader can be programmed into IC1. The fuses will be set correctly by the software.

The cheaper In-Circuit programmers for the Atmel processors usually mimic the STK500 development board. The functions described can be found in the Tools menu. Select the right programmer type, for STK500 you also have to set the right port (this is not the COM-Port provided by the USB/Serial adaptor). Once the Programmer and the port are set, connect the module to this programmer and click “Burn Bootloader” in the Tools menu of the Arduino software.

Instructions how to set up an Arduino Uno for programming the bootloader can be found by Google.

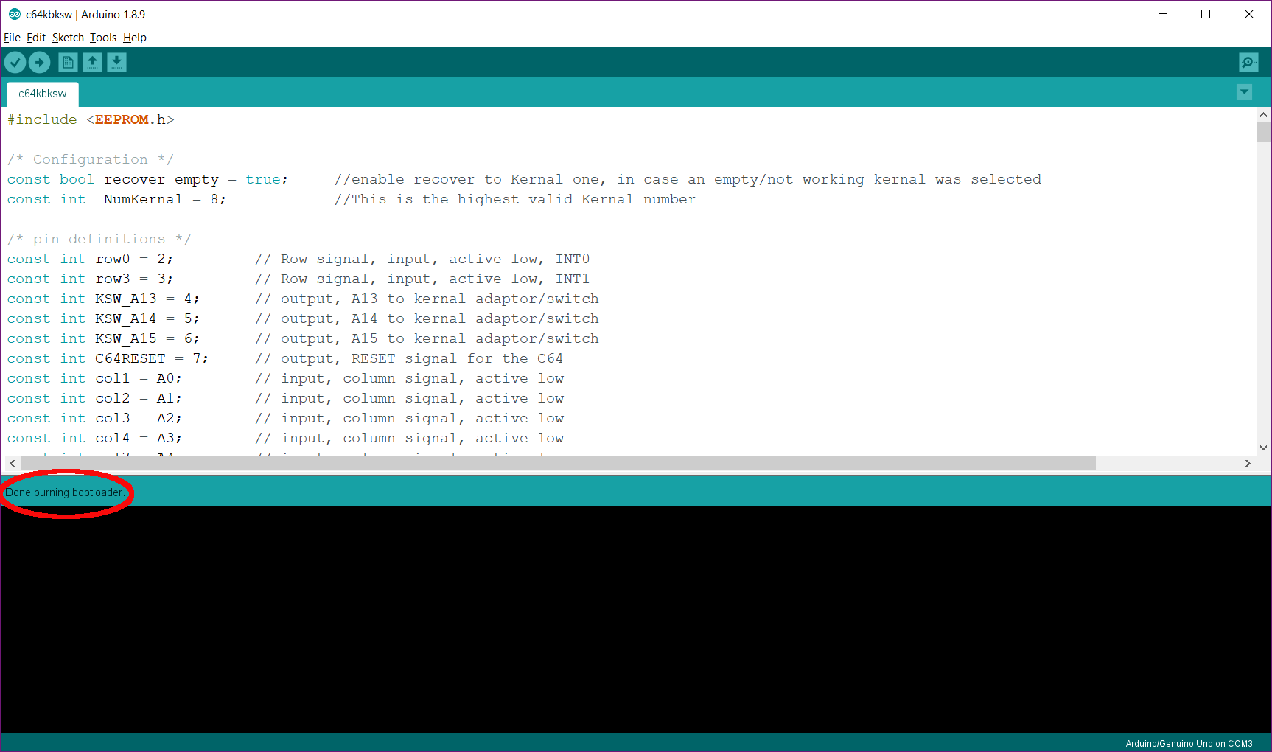
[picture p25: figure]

Figure 11: Burning the bootloader with the Arduino software

Note: the Atmel-ICE Programmer did not work properly for burning the bootloader from the Arduino software. If you own this programmer, you can program the bootloader with the Atmel Studio software.

# Programming the bootloader from Atmel Studio

The Arduino IDE software contains the programming (*.hex) file for the optiboot bootloader, which is used for Arduino Uno etc.


Figure 12: Programming the optiboot bootloader

It can be found here:

C:\Program Files (x86)\Arduino\hardware\arduino\avr\bootloaders\optiboot

The file name is:

optiboot_atmega328.hex

The hex-file can be loaded into the program buffer. Follow the steps like shown in Figure 1 and Figure 2, then select memories and for the Flash, select the file optiboot_atmega328.hex from the location described before.

The fuse settings are not contained in the *.hex file, they have to be programmed separately (see Figure 5).

# Programming the bootloader with TL866II+

The bootloader that can be found in the Arduino software installation (see previous chapter) can also be programmed with the TL866II+ or TL866A. Please refer to Figure 6 to Figure 10. Remember, it is the file optiboot_atmega328.hex. The fuses are set exactly the same and need to be programmed.

# Compiling and Uploading an Arduino sketch

The complete software for the Kernal Switch consists of two parts: the optiboot bootloader and the complied (and actually linked) Arduino sketch (c64kbksw.ino).

Once the bootloader is burnt, the sketch can be transferred via a serial cable as described in document number 128-6-04-00 (Wiring) and a required USB/Serial adaptor.

First the sketch has to be copied to the Arduino sketch folder (usually …\Documents\Arduino\c64kbksw). The sketch has to be opened (File → Open). After the Kernal switch is connected to the USB/serial converter (and this to the PC) via the serial cable and the power is on, the Board (in the Tools menu) has to be set to Arduino/Genuino Uno. Then the Port has to be selected. The USB/Serial adapter will set up as a COM-Port. If there are no other COM-Ports on the PC, it is the only one that will be listed in the (Tools → Port) list. In case you are not sure, press (windows key X) select the Device Manager and look it up in the COM & LPT section (top of the list). It should be something like “USB Serial Port (COMxx)” (xx is the number, you have to remember). In case there is more than one: disconnect the adapter and watch which port disappears and then connect it again and watch what appears.

Once you have found out and set the correct COM Port, the Kernal Switch is connected and powered, you can hit the “right arrow” (= upload icon, 2nd from the left). The sketch will be compiled and the uploaded. Alternatively, select “Upload” from the “Sketch” menu.

If it does not upload, first check the +5V from the USB-Serial adaptor. It can be measured between the +5V and the GND pin of the ICSP connector J2 (see Figure 7). Then, check the cable and finally check the soldering on the PCB (use a magnifying glass or microscope).


Figure 13: Compiling and uploading the sketch

C64_KBCtrl_KSw_ProgG_v1.docx 15.01.2020 10:03 Drafted by Sven Petersen Page 2 of 10 Doc.-No.: 128-6-05-01

C64_KBCtrl_KSw_ProgG_v1.docx 15.01.2020 10:03 Drafted by Sven Petersen Page 1 of 1 Doc.-No.: 128-6-05-00

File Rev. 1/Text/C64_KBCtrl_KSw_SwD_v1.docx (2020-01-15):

C64 Keyboard Controlled Kernal Switch Rev. 1

Software Description

The software is programmed as an Arduino sketch. The purpose for this is to provide the user a way to modify the software for the personal requirements and to upload it via the serial port J3. This requires a cable and USB/serial converter, which will be described in another document.

The name of the Arduino sketch is c64kbksw.ino

The setup routine is initializing the pin modes, set some default logic levels, then reads the configuration jumper to determine, if a short board or a long board is detected. It reads the last selected Kernal number from the EEPROM of the microcontroller. If this is in range, the Kernal will be selected with the output bits KSW_A13 … KSW_K15. In case, the value provided by the EEPROM is out of range, the first possible 8k memory slot will be selected as a Kernal (depending on short board or long board).

The serial port is initialized to 9600, 8N1. The software issues some status information over the serial port (software version, short or long board, keyboard scan detection, number of Kernals, active Kernal number). This can be helpful when debugging the system. No data is received on the serial port.

The Reset timing is configured like this:


Figure 1: Reset timing with EXROM

The timing was provided by bwack and it works on all C64s with all known Kernals. The EXROM signal is only set low while an EXROM reset. For a normal reset, the EXROM signal stays HIGH. The timing is not very critical, an EXROM signal, that is too long will result in a wrong byte count of the free memory on the boot screen (not 38911 bytes free, but a lower number like 30719 bytes free). It just has to stay low for a little bit longer than RESET.

The C64 scans the keyboard by setting the column bits and reading back the row bits. Each of the 8 columns (the vertical structures of the keyboard matrix) is connected to one side of eight keyboard switches. Eight rows (the horizontal structures of the keyboard matrix). While figuring out, which key is pressed, the C64 sets the columns LOW, one by one. Then it reads back the row (as a byte, one bit per row). A bit value 0 (LOW) indicates the key, which is pressed. In case there is just one key pressed, all other row bits are 1 (HIGH).

There are also some other scan activities, which have to be filtered out. E.g. to determine, if a key is pressed (at all), all columns are set to LOW.

In case there is not proper Kernal in the selected memory slot, the C64 crashes (only a software thing, it will not harm the computer). A crashed C64 will not provide any keyboard scanning activities. The software can detect this state and the Kernal Switch will recover to the first Kernal. This is done by reading the column information. In case a value other than “HIGH” will occur in any of the bits before a timeout period elapses, the Kernal is considered to be working.

The two relevant row signals (ROW0 and ROW3) are connected to the two hardware interrupts. Pressing one of the number keys will generate an interrupt. So, there are two interrupt routines. Those will read the column data (the complete PORT C of the processor) and mask the relevant bits (0..4) if those are neither 11111BIN nor 00000BIN, a number key is detected and two flags are set and the column data is preserved, indicating the main loop, that something happened.

The main loop is first trying to find any keyboard activity. Once found, it will not be searched anymore.

Next, the state of the RESTORE key is read. In case the bit is LOW, the restore key is pressed. A count down is started. If the RESTORE key is held for more than 1.5 sec and then released, the C64 will be reset. The time mentioned before will be signalized, in case a power LED is connected to the Kernal Switch. The LED is normally on and will go off for a short time, after the time is reached. After releasing the RESTORE key, the reset signal is issued. The keyboard scan timeout is initialized again.

In case the RESTORE key is held longer than 3 seconds, an EXROM reset will be issued, independent a release of the RESTORE key.

In case the Interrupt Service Routines (ISR) attached to the row bits is informing the main loop, that a number key was pressed, it starts to decode the column information are determines the pressed key. The first key, that is found, will be assumed to be the choice of the user. Multiple keys are not processed.

In case the number is in range, the Kernal number is written to the EEPROM, then the Kernal is selected by setting KSW_A13 … KSW_A15 and resetting the C64. Finally, the main loop waits for 1000µSec. The loop time is not calibrated.

The initial keyboard scan detection might conflict with some cartridges, which do not provide keyboard scanning. One is the dead test cartridge. The Kernal switch can be “deactivated” for such a cartridge, either by pressing RESTORE 0 or by modifying the sketch. (the first the recommended way).

#define LED

//#define buzzer

[…]

/* Configuration */

const bool recover_empty = true; //enable recover to Kernal one, in case an empty/not working kernal was selected

const int NumKernal = 8; //This is the highest valid Kernal number

[…]

#ifdef buzzer

const bool sig_idle = LOW; // idle level of J4, pin 6 (should be HIGH for a power LED)

#else

const bool sig_idle = HIGH; // idle level of J4, pin 6 (should be HIGH for a power LED)

#endif

For this purpose, the constant recover_empty has to be set to false and the constant NumKernal has to be set to the number of Kernals programmed.

For signaling, either an LED or a buzzer with a built-in tone generator can be used. In case the LED is used, it is assumed, that it replaces the power LED. So, it will be on after power up and switched off for signaling. In case a buzzer will be used, it is assumed, that this should be normally off and switched on for signaling. This is configuring the idle level of the signal (sig_idle).

C64_KBCtrl_KSw_SwD_v1.docx 14.01.2020 11:03 Drafted by Sven Petersen Page 2 of 2 Doc.-No.: 128-6-03-01

C64_KBCtrl_KSw_SwD_v1.docx 14.01.2020 11:03 Drafted by Sven Petersen Page 1 of 1 Doc.-No.: 128-6-03-01

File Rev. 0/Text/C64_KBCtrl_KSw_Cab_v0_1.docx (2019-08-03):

C64 Keyboard Controlled Kernal Switch Rev. 0

Wiring v0.1

# Extent of Validity

This document applies to hardware version v0 with firmware version v0.1 or later.

# Connections

There is one required connection, the Control Signals Cable. The Serial Cable to the USB/Serial-converter is optional and only required for uploading an Arduino sketch to the Kernal Switch.


Figure 1: Connectors J3 and J4 of the Keyboard Controlled Kernal Switch

# Control Signal Cable

A wire connection between the keyboard controlled Kernal switch and the Kernal adapter is required to select the desired Kernal. Further on, the module has to reset the C64 after changing to that Kernal.

A recommended connector type is the wide spread Dupont connector. The contacts need to be crimped to the cable—this might be a challenge for some users.


Figure 2: Prefabricated Dupont Cable

Alternatively, prefabricated Dupont cables (female–female) are readily available from eBay and are a suitable prefabricated solution. These prefabricated Dupont cables are usually sold as ribbon cables of up to 40 poles, each wire have an individual connector (Figure 2). The desired amount of wires can simply be peeled off of the ribbon cable. For the C64 short board, 30cm cables are required. For the C64 long board, 10cm cables are an adequate length.

An alternative may be receptacles which fit on pin headers with the cables soldered to them. The next possible solution might be leaving the pin headers on Kernal switch and Kernal adapter not populated and solder in the cables directly.

A pin header (one pin) on the RESET signal of the C64 is required to be soldered. This RESET contact can be found near the user port. Looking from the port side, it is the 3rd contact from the left on the top side. Note, it is not good practice to solder the pin directly at the contact, but rather to a solder pad or via near it.


Figure 3: Reset Contact ASSY 250425 (identical to ASSY 250407) – Long Board


Figure 4: Reset Contact ASSY 250469 (front pin of C90) – Short Board


Figure 5: Connector of the Kernal Adapter


Figure 6: Connecting EXROM (short board)

Figure 6 shows the location of the EXROM signal at the expansion port. It is the same for all ASSYs. A one-pin pin header can easily be soldered to the connector lead of the expansion port. A one pin Dupot connector is required to connect a cable to it. A 220Ω resistor soldered to that cable and covered with a shrinkable sleeve is required to prevent a short circuit with the EXROM signal of some cartridges. For a long board, the required cable is approximately 30cm long. The cable is connected to J4, Pin 5 (RS1). This pin will act as an EXROM pin in Software version 0.1 or later.

The required connections are:

Kernal Switch J4 | Kernal Adaptor JP1 | C64 Mainboard
A13 | A13 | -
A14 | A14 | -
A15 | A15 | -
| - | RESET Pin (Figure 3 & Figure 4)
RS1 | - | EXROM (via 220Ω)

Although the C64 long boards and C64 short boards require different Kernal adapters, both connectors are the same, as indicated in Figure 5.


Figure 7: Wiring of ASSY 250425

Figure 7 shows the wiring of ASSY 250425 (ASSY 2502407 is similar). The grey cable is the reset signal, which is attached to the RESET pin header that was installed previously.


Figure 8: Wiring of ASSY 250469

Figure 8 shows the wiring of ASSY 250469 (short board). Again, the grey cable is the RESET signal, which is attached to the previously soldered RESET pin near the user port.

# Serial Cable

The Serial Cable can vary, depending on the used USB/Serial adapter board. An FT232 based adapter is recommended, which is widely used, provides +3.3V and 5V operation and driver software up to Windows 10.

The USB/Serial adaptor provides VCC (+5V) to the module. This is useful while programming the microcontroller but is not recommended if the module is inserted in the C64 and the computer is powered by it. In this case, the C64 would be powered via the USB interface of the computer. This will not damage the C64, however, for proper operation, the VCC should be interrupted or switched off. The serial interface can be helpful while debugging.

Again, the recommended connector type are Dupont connectors with the alternative of using receptacles, which also fit on standard pin headers. Direct soldering is not recommended.


Figure 9: Serial Cable

Notice: During testing of the Kernal Switch, the C64 sometimes would not start. A ground loop was identified as the cause (mains → PC → USB → Adapter → Serial Cable → Kernal Switch → C64 → C64 Power Supply → mains). The power-on failure was resolved after interrupting the ground loop and the issue did not reoccur.

C64_KBCtrl_KSw_Cab_v0_1.docx 03.08.2019 13:14 Drafted by Sven Petersen Page 5 of 5 Doc.-No.: 128-6-04-00.1

C64_KBCtrl_KSw_Cab_v0_1.docx 03.08.2019 13:14 Drafted by Sven Petersen Page 1 of 1 Doc.-No.: 128-6-04-00.1

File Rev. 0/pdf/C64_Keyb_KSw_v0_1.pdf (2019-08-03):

# Project Documentation

## Commodore C64 – Keyboard Controlled Kernal Switch

## Project number: 128

## Revision: 0

## Date: 14.06.2019


Disclaimer.docx | 06.07.2019 17:45
Drafted by Sven Petersen | Page 1 of 1

### Disclaimer

The usage of the described hardware and the information contained in the documents are at own risk. The author cannot be made liable for the correctness of the development and/or the documentation. It is assumed, that the assembly and installation of the hardware and software is performed by a person of sufficient expertise. The work has to be carried out with care, since it might risk damaging the hardware or the computer it is to be installed in.

C64_KBCtrl_KSw_ModD_v0_1.docx | | 03.08.2019 13:28
Drafted by Sven Petersen | Page 1 of 7 | Doc.-No.: 128-6-01-00.1

### C64 Keyboard Controlled Kernal Switch Rev. 0

### Module Description v0.1

Table of Content

## Extent of Validity

This document applies to hardware version v0 with firmware version v0.1 or later.

## Introduction

The C64 Keyboard Controlled Kernal Switch is a module that passively watches the scan activity of the C64 keyboard and is capable of setting the higher address bits for Kernal adaptors, similar to project number 123 C64 Kernal-Adaptor/Switch for Short Boards that can address up to 7 Kernals, project number 124 C64 Kernal-Adaptor/Switch for Long Boards that can address up to

### 8 Kernals and/or the Character Set Adaptor project number 126 C64 CHARSET-Adaptor/Switch

that can address 16 character sets.

A RESET signal is provided to reset the C64 while/after selecting the Kernal via the three most

significant EPROM address bits. One pin (RESIO1) is dedicated to the EXROM signal for the EXROM-Reset (aka Unstoppable Reset). One excess IO-pins of the processor Atmel ATmega328p is routed to the pin header J4 for future use.

C64_KBCtrl_KSw_ModD_v0_1.docx | | 03.08.2019 13:28
Drafted by Sven Petersen | Page 2 of 7 | Doc.-No.: 128-6-01-00.1

The ATmega328p can be configured with an Arduino Uno. A pin header provides access to the serial interface for uploading the compiled Arduino sketches. Initial programming is performed via the ICSP connector J2.

The board fits between the keyboard connector of the C64 mainboard and the keyboard itself. All keyboard signals are interconnected and some keyboard signals are monitored by the micro controller.

Watch a brief overview video: http://bit.ly/C64KbKernalSwitch-Intro

## Usage of the Kernal Switch

To make use of the Kernal Switch, more than one Kernal should be programmed to the EPROM on the EPROM adaptor. The Kernal can be selected by pressing RESTORE and a number key simultaneously. The Kernal, determined by the number will be selected and the C64 will be reset. This selection is non-volatile and will be effective even after switching off the C64.

Holding down the RESTORE key for about 2-3 seconds and then releasing it (without pressing a number), a reset of the C64 is performed. Holding down the RESTORE key for longer (about
4 seconds), the “unstoppable” EXROM reset will be performed (software v0.1 or later).

In case an empty Kernal memory slot is selected, the C64 will crash, since there is no Kernal found. In this case, the C64 does not perform a keyboard scan and since the Kernal Switch is only listening to the keyboard scanning, but does not perform any keyboard scan, the Kernal number cannot be set manually anymore. After several seconds without keyboard scan, the Kernal switch will automatically recover to the first Kernal and reset the C64. This will recover the system.

Some cartridges will not perform a keyboard scan (such as the Dead Test cartridge). The recovery mechanism will conflict with this kind of cartridge and reset the C64 after several seconds. To circumvent this problem, it is possible to deactivate the Kernal switch by pressing RESTORE 0 (zero). This will switch to the first Kernal and set a non-volatile flag. After switching off the C64 and inserting the cartridge, no keyboard activity timeout will be performed, the cartridge will work normally.

After the cartridge was removed, the first Kernal will be executed and (of course) a normal keyboard scan will be performed. Selecting a Kernal with RESTORE and a number will activate the Kernal Switch again and the new selection will be effective.

## The Unstoppable (EXROM) Reset

This sort of reset will also assert the /EXROM-Signal (which has to be connected to J4, Pin 5 (RS1) via a 220Ω resistor). The background for this is a trick, that some software (e.g. Gyruss, PAC-MAN or Poltergeist) tries to prevent a normal reset of the C64 as kind of a copy/hacking protection. A (fake) cartridge signature is written to the RAM at address $8000 (HEX) and the
following bytes. This consists of the cold start vector, the NMI redirection vector and a “CBM80”
signature in RAM. On a normal reset, the Kernal finds the signature in RAM and redirect the vectors, mentioned before. This way, after playing these games, the RESET does not work well and other games cannot be loaded. With the EXROM reset, a normal boot can be accomplished. Nevertheless, the signature stays in RAM (even a couple of seconds without power). The next reset will still get redirected by this fake cartridge signature.

The destruction of the signature is required and can be accomplished by the instruction


C64_KBCtrl_KSw_ModD_v0_1.docx | | 03.08.2019 13:28
Drafted by Sven Petersen | Page 3 of 7 | Doc.-No.: 128-6-01-00.1

POKE32772,0

and another (normal or EXROM) reset. This POKE changes the C od CBM80, on boot up, this signature is not found and the cold start and NMI vectors are not modified. The C64 is working again.

It was observed, that the fake signature stays intact even after several seconds (maximum time was

### 20 secs) of power off. The C64 might boot up to a black screen or even shows parts of the

previous game. This has created some spooky experience after playing Poltergeist. An EXROM reset and the procedure described before will fix this problem. Also switching off the C64 for a minute or longer will help.

Some cartridges hold the EXROM signal HIGH. In this case, the EXROM reset might not work. To prevent a short circuit, the 220Ω resistor mentioned before is inserted into the cable between J4, Pin 5 and EXROM.

The Final Cartridge III (+) does not work with the EXROM reset. It has a very good reset switch, anyways.

## Assembly

It is assumed, that the person who assembles the Kernal Switch is experienced in soldering. First the SMD parts should be soldered, the bottom entry receptacle J1 should be soldered last can be aligned to the holes in the board using the pin header J5. Pin2 of J2 has to be clipped (refer to Figure 1) and the connector has to be inserted into the holes from the solder side. Then J1 has to be placed over those pins and the connector has to be aligned in a way that it is centered on the J1 silk screen drawing and the SMD pins are in the middle of the solder pads (refer to Figure 2). Then one pin has to be soldered. Then the connector might need to be corrected and a second pin can be soldered. If the pin header inserts easily from the bottom, all other pins can be soldered.

Figure 1: Preparation of J5 (clipping off the 2nd pin)

Figure 2: Centering of J1

Finally, the through-hole parts have to be soldered.


C64_KBCtrl_KSw_ModD_v0_1.docx | | 03.08.2019 13:28
Drafted by Sven Petersen | Page 4 of 7 | Doc.-No.: 128-6-01-00.1

Close (or leave open) the solder bridge CP1, depending whether a short board (ASSY 250469, close CP1) or a long board (all other ASSY numbers, leave CP1 open) is present in the C64.

To prevent the components of the Kernal Switch from making contact with any parts of the C64 mainboards, the area top and bottom of the keyboard connectors can be taped with duct or gaffer tape.

After being completely assembled, the micro controller IC1 (ATmega238P) has to be programmed. Refer to document number 128-6-05-00 (Programming Guide).

Figure 3: CP1 configured for short board (left) and long board (right)

For wiring the Kernal Adaptor, the Kernal Switch and the C64, refer to document number 128-6-04-00.1 (Wiring).

The Assembly of the Kernal Adaptor might require de-soldering the Kernal ROM U4 and installing a socket.

## Troubleshooting

In case the C64 does not start properly, make sure that the Kernal Adaptor is inserted properly into the socket and the EPROM is properly programmed. At least the first Kernal has to be programmed. The Kernal Switch should sit firmly on the keyboard connector and do not make electrical contact with any component leads of the C64 mainboard.

The Atmega328P has to be programmed with either the production file or the *.hex and the fuses have to be set properly (refer to document 128-6-05-00: Programming Guide).

Also, it is important to open or close the configuration solder bridge CP1 on the module to determine between a short and a long board. For C64 short boards, the solder bridge has to be closed, the BASIC has to be in the first 8k of the EPROM and a Kernal (original recommended) has to be in the 2nd 8k of the EPROM.

In case the Kernals do not switch in the sequence as they were programmed into the EPROM, most likely, the wiring between the Kernal Switch and the Kernal Adapter is wrong (refer to document 128-6-04-00: Wiring).

Check, if the RESET pin is really connected to RESET of the C64. Again, check the cable to the RESET pin. Also check the EXROM pin and the cable.

In case it is not working at all, remove the cable between the Kernal Switch and the Kernal Adaptor and set jumpers. Set all three jumpers (A13, A14, A15) for a long board and the jumpers A14 and A15 for a short board. In case it is working now, the Kernal Switch is selecting

C64_KBCtrl_KSw_ModD_v0_1.docx | | 03.08.2019 13:28
Drafted by Sven Petersen | Page 5 of 7 | Doc.-No.: 128-6-01-00.1

the wrong Kernal (maybe an empty 8k slot). Again, check the cable, measuring the pins A13, A14 and A15 on the J4 with a multimeter. Keep in mind that the first Kernal for a short board is 001BIN and for a long board it is 000BIN. A 0 here is represented by a low voltage (<0.7V) and a 1 is represented by a HIGH voltage (>4V).

If the problem is not solved, checking the solder joints is required. To see, if the software is running on the micro controller, a Serial Cable and a USB/Serial Adaptor plus the Arduino software (Tools → Serial Monitor, set to 9600 baud) might help.

After power up, the software should send messages via the serial cable. The RESTORE key has to be detected and reported (after holding it down) and a number key will be reported too.

Make sure, that the C64 power supply and the PC are connected and that the cables do not for a big loop, as this might prevent proper function. The serial connection is only for programming (in some cases) and for debugging, so it is not a problem if a ground loop causes problems. It was experienced during testing, that with a big ground loop (a couple of square meters) the C64 did not always start properly.

## Keyboard Monitoring

The columns 1-4 and 7 as well as the rows 0 and 3 are connected to IO-pins of the micro controller. The C64 sends a scan bit to the columns, which are HIGH on default. The scan bit is LOW and it is shifted through the columns, one at a time. The rows are read back by the C64. A LOW signal on one or more row bits indicates a pressed key.

The following keyboard scan information can be obtained by the microcontroller:

Column
7 | 4 | 3 | 2 | 1
Row 0 | “1” | “9” | “7” | “5” | “3”
Row 3 | “2” | “0” | “8” | “6” | “4”

It is obvious that only the numerals are being monitored. Further the RESTORE key is connected to the microcontroller.

## Programming Model

Pin | GPIO Arduino | Function | Configuration
30 | PD0 | D0 | RxD | Input | Serial Receive
31 | PD1 | D1 | TxD | Output | Serial Transmit
32 | PD2 | D2 | Row0 | Input, weak pull-up | Active LOW, INT0
1 | PD3 | D3 | Row3 | Input, weak pull-up | Active LOW, INT1
2 | PD4 | D4 | KSW_A13 | Output | Kernal Switch A13
9 | PD5 | D5 | KSW_A14 | Output | Kernal Switch A14
10 | PD6 | D6 | KSW_A15 | Output | Kernal Switch A15
11 | PD7 | D7 | C64RES | Output | Active HIGH
23 | PC0 | A0 | COL1 | Input, weak pull-up | Keyboard column 1
24 | PC1 | A1 | COL2 | Input, weak pull-up | Keyboard column 2
25 | PC2 | A2 | COL3 | Input, weak pull-up | Keyboard column 3
26 | PC3 | A3 | COL4 | Input, weak pull-up | Keyboard column 4
27 | PC4 | A4 | COL7 | Input, weak pull-up | Keyboard column 7
28 | PC5 | A5 | RESTORE | Input, weak pull-up | RESTORE-Key, active LOW

C64_KBCtrl_KSw_ModD_v0_1.docx | | 03.08.2019 13:28
Drafted by Sven Petersen | Page 6 of 7 | Doc.-No.: 128-6-01-00.1
Pin | GPIO Arduino | Function | Configuration
12 | PB0 | D8 | SHORT_BRD | Input | Short Board, active LOW
13 | PB1 | D9 | RS1 | Output, HIZ | Used as EXROM pin
14 | PB2 | D10 | RS2 | TBD | Reserve IO Pin#2

## Connectors

### J1 - Keyboard connector to mainboard

Bottom Entry receptacle (1x20p, pitch 2.54mm) – Harwin M20-7862042

Pin Signal | Pin Signal
1 | GND | 11 | ROW1 (PB1)
2 | No pin | 12 | ROW0 (PB0)
3 RESTORE | | 13 COL0 (PA0)
4 | +5V | 14 | COL6 (PA6)
5 | ROW3 (PB3) | 15 | COL5 (PA5)
6 | ROW6 (PB6) | 16 | COL4 (PA4)
7 | ROW5 (PB5) | 17 | COL3 (PA3)
8 | ROW4 (PB4) | 18 | COL2 (PA2)
9 | ROW7 (PB7) | 19 | COL1 (PA1)
10 | ROW2 (PB2) | 20 | COL7 (PA7)

### J2 – In System Programming

2x3 box pin header (2.54mm pitch). This connector is used for the initial in-system programming of the ATmega238p (IC1). 89

Pin Signal | Pin Signal
1 | MISO | 2 | +5V
3 | SCK | 4 | MOSI
5 | RESET (IC1) | 6 | GND

### J3 – Serial/Debug

1x5 pin header (2.54mm pitch). In Arduino mode (after programming the Arduino boot loader), a USB/serial converter can be used to transfer the compiled Arduino sketches and for debugging with the serial monitor.

Pin | Signal | USB/Serial converter
1 | GND | GND
2 | +5V | +5V
3 | TxD (output) | RX
4 | RxD (input) | TX
5 | DTR (input) | DTR

### J4 – IO-Connector

1x6 pin header (2.54mm pitch)

C64_KBCtrl_KSw_ModD_v0_1.docx | | 03.08.2019 13:28
Drafted by Sven Petersen | Page 7 of 7 | Doc.-No.: 128-6-01-00.1

This connector outputs the control signals of this board. It is for being connected to the Kernal and/or keyboard adapter. It also provides two reserved IO-Pins for later use.

Pin | Signal | Function
1 | KSW_A13 | Kernal Switch/Adapter A13
2 | KSW_A14 | Kernal Switch/Adapter A14
3 | KSW_A15 | Kernal Switch/Adapter A15
4 C64_RESET | | RESET signal for the C64 (to be connected to a RESET point on the mainboard
5 | RESIO1 | Used as EXROM signal (software v0.1 or later)
6 | RESIO2 | Reserved IO

### J5 - Keyboard connector

Pin header (1x20p, pitch 2.54mm) – Pin 2 clipped off (no pin)

Pin Signal | Pin Signal
1 | GND | 11 | ROW1
2 | No pin | 12 | ROW0
3 RESTORE | | 13 COL0
4 | +5V | 14 | COL6
5 | ROW3 | 15 | COL5
6 | ROW6 | 16 | COL4
7 | ROW5 | 17 | COL3
8 | ROW4 | 18 | COL2
9 | ROW7 | 19 | COL1
10 | ROW2 | 20 | COL7

## Documents

Document | Document Number
Disclaimer | -
Module Description (this document) | 128-6-01-**
Schematic | 128-1-01-**
PCB prints | 128-2-01-**
Functional Description | 128-6-02-**
Software Description | 128-6-03-**
Wiring | 128-6-04-**
Programming Guide | 128-6-05-**
Testing | 128-6-06-**
Bill of Material | 128-5-01-**.*

** depends on revision

## Revision History

### Rev. 0

- Prototype (fully functional)
- EXROM modification helpful (see The Unstoppable (EXROM) Reset)









C64_KBCtrl_KSw_FunD_v0_1.docx | | 03.08.2019 13:21
Drafted by Sven Petersen | Page 1 of 1 | Doc.-No.: 128-6-02-00.1

### C64 Keyboard Controlled Kernal Switch Rev. 0.1

### Functional Description

This document applies to hardware version v0 with firmware version v0.1 or later.

IC1 is an ATmega328P processor and it provides the functionality of an Arduino Uno. X1 is the 16MHz quartz and forms the quartz oscillator together with C4, C5 and R3. J2 is the connector for in-system programming of IC1. It is required at least once for writing the Arduino bootloader.

A serial interface for debugging is provided on J3. This interface has a TTL-level serial signals. To connect it to a PC, a USB/serial converter board is required. Once the bootloader is programmed to IC1, the serial interface can serve to transfer a compiled Arduino sketch to the Kernal Switch. In case this serial interface is not required and J3, C7, D1and R7 can stay unpopulated.

The Kernal Switch has to distinguish between C64 long boards and C64 short boards; this because with a short board BASIC resides in the lowest 8k of the EPROM.

A[15..13] (of the EPROM) ranges from 001BIN to111BIN. With a long board all 8k memory slots can serve as a Kernal so A[15..13] range from 000BIN to 111BIN.

- CP1 serves for setting the board type: (i) to configure a long board leave CP1 open; (ii) to configure a short board CP1 must be closed by a simple solder bridge.
- The transistor Q1 serves for resetting the C64 and provides the required open collector

output. A HIGH level on C64RES will pull the output C64_RESET LOW, which then resets the C64.
- J4 is the pin header, which provides the signals for selecting the Kernal (KSW_A13 ..

KSW_A15), for resetting the C64 ( C64_RESET ), the EXROM signal (on RESIO1) and one GPIO pins (RESIO2) which is not assigned to a purpose, yet.
- J1 is a bottom entry receptacle, the pins of the keyboard connector are inserted through holes in the PCB into this connector from below. All keyboard signals are connected here. J1 provides the supply voltage (+5V) for the circuit on the Kernal switch.
- J5 is the pin header for connecting the keyboard. All (keyboard) signals from J1 are connected to the same pin on J5.
- Only the required scan signals are connected to IC1. That is column 1, 2, 3, 4 and 7, as well as row 0 and 3. The row signals are pulled LOW in case a key in the row is being pressed. These row signals are connected to the two external interrupt pins (INT0 and INT1)
of IC1. The key scan signals have to be configured as “input with weak pull-up resistor”,
since the TTL logic of the C64 interprets an open input as a HIGH input, while it is an illegal state for the MOS logic of IC1.

C64_KBCtrl_KSw_SwD_v0_1.docx | | 03.08.2019 14:48
Drafted by Sven Petersen | Page 1 of 2 | Doc.-No.: 128-6-03-00.1

### C64 Keyboard Controlled Kernal Switch Rev. 0

### Software Description v0.1

The software is programmed as an Arduino sketch. The purpose for this is to provide the user a way to modify the software for the personal requirements and to upload it via the serial port J3. This requires a cable and USB/serial converter, which will be described in another document.

The name of the Arduino sketch is c64ksksw.ino

The setup routine is initializing the pin modes than reads the configuration jumper to determine , if a short board or a long board is detected. It reads the last selected Kernal number from the EEPROM of the microcontroller. If this is in range, the Kernal will be selected with the output

### bits KSW_A13 … KSW_K15. In case, the value provided by the EEPROM is out of range, the

first possible 8k memory slot will be selected as a Kernal (depending on short board or long board).

The C64 scans the keyboard by setting the column bits and reading back the row bits. Each of the 8 columns (the vertical structures of the keyboard matrix) is connected to one side of eight keyboard switches. Eight rows (the horizontal structures of the keyboard matrix). While figuring out, which key is pressed, the C64 sets the columns LOW, one by one. Then it ready back the row (as a byte, one bit per row). A bit value 0 (LOW) indicates exactly the key, which is pressed. In case there is just one key pressed, all other row bits are 1 (HIGH).

There are also some other scan activities, which have to be filtered out. E.g. to determine, if a key is pressed (at all), all columns are set to LOW.

In case there is not proper Kernal in the selected memory slot, the C64 crashes (only a software thing, it will not harm the computer). A crashed C64 will not provide any keyboard scanning activities. The software can detect this state and the Kernal Switch will recover to the first Kernal.
This is done by reading the column information. In case a value other than “HIGH” will occur
in any of the bits before a timeout period elapses, the Kernal is considered to be working.

The two relevant row signals (ROW0 and ROW3) are connected to the two hardware interrupts. Pressing one of the number keys will generate an interrupt. So, there are two interrupt routines. Those will read the column data (the complete PORT C of the processor) and mask the relevant bits (0..4) if those are neither 11111BIN nor 00000BIN, a number key is detected and two flags are set and the column data is preserved, indicating the main loop, that something happened.

The main loop is first trying to find any keyboard activity. Once found, it will not be searched anymore.

Figure 1:Timing of the (EXROM) reset

Next, the state of the RESTORE key is read. In case the bit is LOW, the restore key is pressed. A time count is started. If the RESTORE key is held between 1500 and 3000 main loop cycles

C64_KBCtrl_KSw_SwD_v0_1.docx | | 03.08.2019 14:48
Drafted by Sven Petersen | Page 2 of 2 | Doc.-No.: 128-6-03-00.1

(appr. 2-4 seconds), the C64 will be reset. If the RESTORE key is further held, an EXROM Reset is performed. The reset signal is issued for 400ms. The keyboard scan timeout is initialized again. The timing of the EXROM reset is not very critical, other timings have been tested and functioned as well.

In case the Interrupt Service Routines (ISR) attached to the row bits is informing the main loop, that a number key was pressed, it starts to decode the column information are determines the pressed key. The first key, that is found, will be assumed to be the choice of the user. Multiple keys are not processed.

In case the number is in range, the Kernal number is written to the EEPROM, then the Kernal is

### selected by setting KSW_A13 … KSW_A15 and resetting the C64. Finally, the main loop waits

for 1000µSec. The loop time is not calibrated.

The initial keyboard scan detection might conflict with some cartridges, which do not provide
keyboard scanning. One is the dead test cartridge. The Kernal switch can be “deactivated” for
such a cartridge, either by pressing RESTORE 0 or by modifying the sketch. (the first the recommended way).

/* Config uration */

const bool recover_empty = true; | //enable recover to Kernal one, in
case an empty/not working kernal was selected
const int | NumKernal = 8; | //This is the highest valid Kernal
number

For this purpose, the constant recover_empty has to be set to false and the constant NumKernal has to be set to the number of Kernals programmed.


C64_KBCtrl_KSw_ProgG_v0.docx | | 06.07.2019 17:49
Drafted by Sven Petersen | Page 1 of 10 | Doc.-No.: 128-6-05-00

### C64 Keyboard Controlled Kernal Switch Rev. 0

### Programming Guide

## Introduction

The microcontroller on the Kernal switch has to be programmed to function properly. There are several ways of transferring the program into IC1.

Since the program is based on the Arduino IDE, the program can be considered to consist of three parts:

- the Arduino Bootloader (optiboot_atmega328.hex)
- the fuses
- the compiled sketch (c64kbksw.ino)

The bootloader will enable the Arduino IDE to transfer (compiled) sketches via the serial cable into the ATmega328P microcontroller on the Kernal switch.

The fuses are the configuration of the ATmega328P. If those are not set properly, the Kernal switch will not work like desired.

The sketch is the source code of the program. It needs to be compiled and uploaded by the Arduino IDE (=Integrated Development Environment).

## One Pass Programming

It is possible to transfer the bootloader, the compiled sketch and the fuses in one pass. That requires a suitable programmer (like the Atmel ICE, an SDK500 based programmer or another supported programming hardware). Further on, the Atmel Studio software is required. It is the IDE for writing software for Atmel controllers and programming the chips.

Figure 1: Atmel Studio IDE


C64_KBCtrl_KSw_ProgG_v0.docx | | 06.07.2019 17:49
Drafted by Sven Petersen | Page 2 of 10 | Doc.-No.: 128-6-05-00

The programming data is c64kbksw_v0_0.elf (or a later version). It was read out from an already programmed Kernal switch with a programmer and stored.

### Step 1

Start the Atmel Studio IDE and select the Device Programming Tool as shown in Figure 1.

### Step 2

Configure the tool (=the programmer), the device (ATmega328P), the interface (ISP = in-system programming) and click “Apply”, like in Figure 2.

Figure 2: Device Programming
When you click “Read”, the Device signature should be displayed and the Target Voltage should be shown (about 5V). In case, it does not, the module needs to be powered externally with 5V (connector J3). It can be done with the USB/Serial adaptor and the serial cable, or just a bench power supply.

### Step 3

Click “Production File”, then select the ELF production file (c64kbksw_v0_0.elf or later version) from the location, where you have stored it. Check “Flash” and “Fuses”, also “Erase memory before programming” and “verify programmed content”, like shown in Figure 3.
Now, click the “Program” button. The programming will start.

While the programming, the status is reported in the lower part of the window. This is marked yellow in Figure 4. Erasing, Programming Flash and Verifying, Programming fuses and Verifying should all
be reported “OK”.

Now, the program (bootloader and fuses included) is completely transferred to the ATmega328P. The module should be fully functional now. Since it contains the bootloader, the Kernal switch can be modified with the Arduino IDE and a serial cable.

C64_KBCtrl_KSw_ProgG_v0.docx | | 06.07.2019 17:49
Drafted by Sven Petersen | Page 3 of 10 | Doc.-No.: 128-6-05-00

Figure 3: Production File settings

Figure 4: Programming the device

The fuses of the ATmega328P should be set like this:

C64_KBCtrl_KSw_ProgG_v0.docx | | 06.07.2019 17:49
Drafted by Sven Petersen | Page 4 of 10 | Doc.-No.: 128-6-05-00
- EXTENDED: | 0xFD
- HIGH: | 0xDE
- LOW: | 0xFF

This can be checked with the Device Programming tool like in Figure 5.

Figure 5: Fuses


C64_KBCtrl_KSw_ProgG_v0.docx | | 06.07.2019 17:49
Drafted by Sven Petersen | Page 5 of 10 | Doc.-No.: 128-6-05-00

## One Pass Programming TL866

The ATmega328P can be programmed either with a TQFP32 adaptor or via the ICSP port. In both cases, the program (c64kbksw_v0_0.hex or a later version) has to loaded to the programming buffer (the format is Intel HEX) and the fuses have to be set manually (see Figure 6). The file contains the bootloader and the compiled sketch. No further programming is required.

Figure 6: Correct setting of the fuses
This setting can be found in the “Config” tab.

Without a TQFP32 adaptor, the processor can be programmed in-system. The TL866II+ and the TL866A provide such an ICSP port. As a cable, a 6-wire Dupont cable will work (see Figure 9).

The connections should be made according to Figure 8.


C64_KBCtrl_KSw_ProgG_v0.docx | | 06.07.2019 17:49
Drafted by Sven Petersen | Page 6 of 10 | Doc.-No.: 128-6-05-00

Figure 7: Pinout of the ICSP connector J2

Figure 8: ICSP connection from TL866II+ to ATmega328P

The Dupont cable needs to be connected correctly, the connection has to be double checked to prevent harming the module or the programmer. In case, the repeated programming is intended, it might make sense to build a cable with a real 6x1 and 3x2 pin Dupont crimp housing (the 1pin crimp housings of the cable can be uninstalled).

When programming the controller, make sure, the code memory and the fuses are checked (Figure 10).


C64_KBCtrl_KSw_ProgG_v0.docx | | 06.07.2019 17:49
Drafted by Sven Petersen | Page 7 of 10 | Doc.-No.: 128-6-05-00

Figure 9: ICSP with a Dupont cable

Figure 10: Programming the ATmega328P with the TL866II+

## Programming the bootloader from the Arduino IDE

With a supported programmer or a programmer made from an Arduino Uno, the Arduino bootloader can be programmed into IC1. The fuses will be set correctly by the software.

The cheaper In-Circuit programmers for the Atmel processors usually mimic the STK500 development board. The functions described can be found in the Tools menu. Select the right programmer type, for STK500 you also have to set the right port (this is not the COM-Port provided by the USB/Serial adaptor). Once the Programmer and the port are set, connect the module to this
programmer and click “Burn Bootloader” in the Tools menu of the Arduino software.

Instructions how to set up an Arduino Uno for programming the bootloader can be found by Google.


C64_KBCtrl_KSw_ProgG_v0.docx | | 06.07.2019 17:49
Drafted by Sven Petersen | Page 8 of 10 | Doc.-No.: 128-6-05-00

Figure 11: Burning the bootloader with the Arduino software

Note: the Atmel-ICE Programmer did not work properly for burning the bootloader from the Arduino software. If you own this programmer, you can program the bootloader with the Atmel Studio software.

## Programming the bootloader from Atmel Studio

The Arduino IDE software contains the programming (*.hex) file for the optiboot bootloader, which is used for Arduino Uno etc.

Figure 12: Programming the optiboot bootloader

C64_KBCtrl_KSw_ProgG_v0.docx | | 06.07.2019 17:49
Drafted by Sven Petersen | Page 9 of 10 | Doc.-No.: 128-6-05-00

It can be found here:

C:\Program Files (x86)\Arduino\hardware\arduino\avr\bootloaders\optiboot

The file name is:

optiboot_atmega328.hex

The hex-file can be loaded into the program buffer. Follow the steps like shown in Figure 1 and Figure 2, then select memories and for the Flash, select the file optiboot_atmega328.hex from the location described before.

The fuse settings are not contained in the *.hex file, they have to be programmed separately (see Figure 5).

## Programming the bootloader with TL866II+

The bootloader that can be found in the Arduino software installation (see previous chapter) can also be programmed with the TL866II+ or TL866A. Please refer to Figure 6 to Figure 10. Remember, it is the file optiboot_atmega328.hex. The fuses are set exactly the same and need to be programmed.

## Compiling and Uploading an Arduino sketch

The complete software for the Kernal Switch consists of two parts: the optiboot bootloader and the complied (and actually linked) Arduino sketch (c64kbksw.ino).

Once the bootloader is burnt, the sketch can be transferred via a serial cable as described in document number 128-6-04-00 (Wiring) and a required USB/Serial adaptor.

First the sketch has to be copied to the Arduino sketch folder (usually …\Documents\Arduino\c64kbksw). The sketch has to be opened (File → Open). After the Kernal switch is connected to the USB/serial converter (and this to the PC) via the serial cable and the power is on, the Board (in the Tools menu) has to be set to Arduino/Genuino Uno. Then the Port has to be selected. The USB/Serial adapter will set up as a COM-Port. If there are no other COM-Ports on the PC, it is the only one that will be listed in the (Tools → Port) list. In case you are not sure, press (windows key X) select the Device Manager and look it up

### in the COM & LPT section (top of the list). It should be something like “USB Serial Port (COMxx)” (xx is the number, you have to remember). In case there is more than one:

disconnect the adapter and watch which port disappears and then connect it again and watch what appears.

Once you have found out and set the correct COM Port, the Kernal Switch is connected and
powered, you can hit the “right arrow” (= upload icon, 2nd from the left). The sketch will be compiled and the uploaded. Alternatively, select “Upload” from the “Sketch” menu.

If it does not upload, first check the +5V from the USB-Serial adaptor. It can be measured between the +5V and the GND pin of the ICSP connector J2 (see Figure 7). Then, check the cable and finally check the soldering on the PCB (use a magnifying glass or microscope).


C64_KBCtrl_KSw_ProgG_v0.docx | | 06.07.2019 17:49
Drafted by Sven Petersen | Page 10 of 10 | Doc.-No.: 128-6-05-00

Figure 13: Compiling and uploading the sketch

C64_KBCtrl_KSw_TestD_v0.docx | | 06.07.2019 17:44
Drafted by Sven Petersen | Page 1 of 5 | Doc.-No.: 128-6-06-00

### C64 Keyboard Controlled Kernal Switch Rev. 0

### Prototype Testing

## Test Description

The test was executed with different models of the C64 mainboard.

- ASSY 250407 (Long Board)
- ASSY 250425 Rev. A (Long Board) in a Commodore 64C case
- ASSY 250469 Rev. 4 (Short Board)

The Kernal Adapter (long board, short board) was selected to fit the C64 mainboard and the Kernal Switch was configured with the solder bridge CP1 accordingly.

All mainboards had a pin header (1 pin) installed to access their RESET-signal. The Kernal adapter and the Kernal switch were installed and wired.

The Kernal Adapter (Rev. 0) and the Kernal Switch (Rev. 0) was installed, a firm seat was checked for and the cable were made and installed.

The test was carried out with seven different Kernals:

Number Kernal
1 Original Commodore
2 JiffyDOS (6.01)
3 JaffyDOS (1.3)
4 EXOS v3
5 SpeedDOS
6 DolphinDOS 2.0
7 Turbo Tape v0.1
8 No Kernal (long board only)

The EPROM of the short board version contained Commodore BASIC in the first 8k and the last 8k of the long board EPROM was left empty.

## Mechanical Fit

Installation ASSY 250469 Rev. 4: The Kernal Adaptor is not colliding with any other components, some had to be bend in one direction to give some space to the PCB. The Kernal Switch was above U18, no collision detected.

RP4 had to be bent backward, slightly. All other components were far enough away. The board was seating well, the contact of J1 was sufficient. No contact between the solder side through-hole pads and components of the C64 mainboard. It might be possible to get contact between those and the ground frame of ASSY 250469, when the module is not seated well.

It is recommended to apply electrical insulation tape to the solder side south of the keyboard connectors to prevent this.


C64_KBCtrl_KSw_TestD_v0.docx | | 06.07.2019 17:44
Drafted by Sven Petersen | Page 2 of 5 | Doc.-No.: 128-6-06-00

Figure 1: Installation ASSY250469

Installation ASSY 250425 Rev. A in C64C case:

The module fits on the board, it is seated properly, the contact of J1 is sufficient. The keyboard brackets do not collide with the PCB, the space is sufficient for the ICSP connector J2.

Figure 2: Installation ASSY250425

The protection diodes that are placed on top of other components on most ASSY250425 fit under the PCB. Since it is possible, that these diodes make contact with the through-hole pads of the module, it is required to apply electrical insulation tape the solder side of the board south of the keyboard connectors.


C64_KBCtrl_KSw_TestD_v0.docx | | 06.07.2019 17:44
Drafted by Sven Petersen | Page 3 of 5 | Doc.-No.: 128-6-06-00

Figure 3: Installation ASSY250407 in bread bin case

Installation ASSY 250407 Rev. B in bread bin case:

The module fits on the board, it is seated properly, the contact of J1 is sufficient. The PCB does not collide with the components of the C64 south of the keyboard connector. It might be possible, that the pins of J2 scratch the resistors underneath it.

It is recommended to tape the solder side of the module south of the keyboard connector.

## Test of Functionality

### Long Board Version

The long board can switch between 8 Kernals. The EPROM was programmed with seven Kernals plus an empty 8th 8k EPROM slot.

Holding the RESTORE key
Holding the RESTORE key for several seconds generated a RESET of the C64. This was reported on the serial interface. This test was carried out >20 times.

Switching the Kernals
Pressing the number keys was detected properly and reported on the serial interface. Holding the RESTORE key and pressing a number key lead to changing the Kernal and resetting the C64. This worked like desired. The RESET pulse for the C64 was LOW for approximately 2 seconds.

All seven Kernals were tested several times each. No unwanted behavior was found.

Power Cycle
Switching Kernals and at least 20 power cycles per Kernal were performed. The previously selected Kernal was executed after the power cycle. The value is properly stored in the (non-volatile) EEPROM of the microcontroller. No unwanted behavior was found.

Switching to an Empty Kernal
After selecting a valid Kernal, it was pressed RESTORE 8 to switch to the empty Kernal. The result was a crash of the C64. One character on the screen is cycled quickly, nothing else was visible. After
a timeout of several seconds, the module reported “no keyboard activity” on the serial interface,
switched to Kernal 1 and reset the system. The C64 restarted with Kernal 1 (the original Kernal). The desired recovery procedure worked properly. The test was carried out several times, starting from each of the valid Kernals.

### Short Board Version

The short board can switch between 7 Kernals. The EPROM was programmed with BASIC and seven Kernals.

C64_KBCtrl_KSw_TestD_v0.docx | | 06.07.2019 17:44
Drafted by Sven Petersen | Page 4 of 5 | Doc.-No.: 128-6-06-00

Holding the RESTORE Key
Holding the RESTORE key for several seconds generated a RESET of the C64. This was reported on the serial interface. This test was carried out >20 times.

Switching the Kernals
Pressing the number keys was detected properly and reported on the serial interface. Holding the RESTORE key and pressing a number key lead to changing the Kernal and resetting the C64. This worked like desired. The RESET pulse for the C64 was LOW for approximately 2 seconds.

All seven Kernals were tested several times each. No unwanted behavior was found.

Power Cycle
Switching Kernals and at least 20 power cycles per Kernal were performed. The previously selected Kernal was executed after the power cycle. The value is properly stored in the (non-volatile) EEPROM of the microcontroller. No unwanted behavior was found.

## Test with Cartridges

The following cartridges were tested with the Kernal Switch:

- Final Cartridge 3+
- Power Cartridge
- Dela Dos
- Forth 64
- Diagnostic Rev. 586220
- 1541 Diagnostic/Test
- Ultimate II+
- Dead Test Rev. 781220

Except the Dead Test, all cartridges worked as desired, no unwanted behavior was found. Several power cycles were performed. The Diagnostic Rev. 586220 is configured as an EXROM cartridge, so at least initially, some keyboard scans are found.

The Dead Test cartridge does not perform keyboard scans. Thus, the Kernal Switch will reset the C64 after the time out of several seconds without keyboard scanning. This behavior was expected.

To provide non-interfered operation for this kind of cartridge, the module can be deactivated by pressing RESTORE 0 (zero). This was conducted: The Kernal was changed to Kernal 1. After switching off the C64, installing the Dead Test cartridge and powering up the computer again, the Dead Test was performed properly. The deactivation state was stored properly in the (non-volatile) EEPROM of the ATmega238P. Several tests cycles were performed. After unplugging the cartridge, the deactivation mode was switched off by selecting any of the Kernals. The state of activation was properly reported on serial interface. The desired behavior was shown.

C64_KBCtrl_KSw_TestD_v0.docx | | 06.07.2019 17:44
Drafted by Sven Petersen | Page 5 of 5 | Doc.-No.: 128-6-06-00

## Conclusion

The Keyboard Controlled Kernal Switch is fully functional.

Note: Not all mainboard and case type combinations could be tested. Also, the used parts may vary. An assessment of a proper installation and suitable connector seat of the keyboard connector J5 and the bottom entry connector J1 should be performed with every installation.

Again, it is required to apply electrical insulation tape to the solder side in the area south of the keyboard connectors to prevent short circuit or scratching the parts underneath the module.

Pos. Qty Value Footprint Ref.-No. Comment

1 1 128-2-01-00 2 Layer PCB Rev. 0 2 layer, Cu 35µ, HASL, 101.2mm x 20.0mm, 1.6mm FR4

copper structure on pcb CP1 no part, open Cutpad, close for ASSY250469

1 1x20 1X20 J5 pin header 1x20pin, 2.54mm pitch
1 1x6 1X06 J4 pin header 1x6pin, 2.54mm pitch

5 100n 0805 C1, C2, C3, C6, C7 SMD capacitor

4 10k 0805 R1, R2, R4, R5 SMD resistor, 5% or better

1 1M 0805 R3 SMD resistor, 5% or better
2 1k 0805 R6, R7 SMD resistor, 5% or better

2 22p 0805 C4, C5 SMD capacitor

### 1 ATMEGA328P-AU QFP80P900X90

0X120-32N

IC1 Atmel/Micro Chip, e.g. Farnell 2443176

### 1 BC846B SOT23 Q1 SMD transistor

1 16 MHz/20pF quarz HC49SLF X1 e.g. Fox Electronics, FOXSLF/160-20, Farnell 2063950

### 1 LL4148 SOD80C D1 SMD diode

### 1 M20-7862042 M20-7862042 J1 Harwin, e.g. Farnell 1256661

### 1 WSL 6G 2X03WV J2 box pin header, 2x3pin, 2.54mm pitch

1 1x5 1X05 J3 pin header 1x5pin, 2.54mm pitch

## C64 Keyboard Controlled Kernal Switch Rev. 0

## Bill of Material Rev. 0.0

C64_KbKernalSw_BOM_v0.0.xlsx

Drafted by Sven Petersen Page 1 of 1

03.07.2019 19:17
Doc.No.: 128-5-01-00.0

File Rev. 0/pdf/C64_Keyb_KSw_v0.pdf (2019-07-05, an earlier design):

# Project Documentation

## Commodore C64 – Keyboard Controlled Kernal Switch

## Project number: 128

## Revision: 0

## Date: 14.06.2019


Disclaimer.docx | 03.07.2019 19:08
Drafted by Sven Petersen | Page 1 of 1

### Disclaimer

The usage of the described hardware and the information required in the documents are at own risk. The author cannot be made liable for the correctness of the development and/or the documentation. It is assumed, that the assembly and installation of the hardware and software is performed by a person of sufficient expertise. The work has to be carried out with care, since it might risk damaging the hardware or the computer it is to be installed in.

Trademarks

Arduino, JiffyDOS, TL866, Atmel etc. are (probably) trademarks. They were only used for identification purposes.

C64_KBCtrl_KSw_ModD_v0.docx | | 03.07.2019 19:09
Drafted by Sven Petersen | Page 1 of 5 | Doc.-No.: 128-6-01-00

### C64 Keyboard Controlled Kernal Switch Rev. 0

### Module Description

## Introduction

The C64 Keyboard controlled Kernal switch is a module, which is (passively) watching some the scan activity of the C64 keyboard and is capable of setting the higher address bits for Kernal adapters, like project number 123 (C64 Kernal-Adaptor/Switch (Short Board), up to 7 Kernals), project number 124 (C64 Kernal-Adaptor/Switch (Long Board), Up to 8 Kernals) and/or the character set adaptor project number 126 (C64 CHARSET-Adaptor/Switch, 16 character sets). A RESET -signal is provided to reset the C64 while/after selecting the Kernal via the three most significant EPROM address bits. Two excess IO-pins of the processor Atmel ATmega328p are routed to the pin header J4 for future use.

The ATmega328p can be configured as Arduino Uno, a pin header is providing access to the serial interface for uploading the compiled Arduino sketches. Initial programming will be performed via the ICSP connector J2.

The board fits between the keyboard connector of the C64 mainboards and the keyboard itself. All keyboard signals are interconnected, some keyboard signals are monitored by the micro controller.

## Usage of the Kernal Switch

To make use of the Kernal Switch, more than one Kernal should be programmed to the EPROM on the EPROM adaptor. The Kernal can be selected by Pressing RESTORE and a number key simultaneously. The Kernal, determined by the number will be selected and the C64 will be reset. This selection is non-volatile and will be effective even after switching off the C64.

Holding down the RESTORE key for a couple of seconds without pressing a number, a reset of the C64 is performed.

In case an empty Kernal memory slot is selected, the C64 will crash, since there is no Kernal found. In this case, the C64 does not perform a keyboard scan and since the Kernal Switch is only listening to the keyboard scanning, but does not perform any keyboard scan, the Kernal number cannot be set manually anymore. After several seconds without keyboard scan, the Kernal switch will automatically recover to the first Kernal and reset the C64. This will recover the system.

Some cartridges will not perform a keyboard scan (such as the Dead Test cartridge). The recovery mechanism will conflict with this kind of cartridge and reset the C64 after several seconds. To circumvent this problem, it is possible to deactivate the Kernal switch by pressing RESORE 0 (zero!). This will switch to the first Kernal and set a non-volatile flag. After switching off the C64 and inserting the cartridge, no keyboard activity timeout will be performed, the cartridge will work as usual.

After the cartridge was removed, the first Kernal will be executed and (of course) a normal keyboard scan will be performed. Selecting a Kernal with RESTORE and a number will activate the Kernal Switch again and the new selection will be effective.

C64_KBCtrl_KSw_ModD_v0.docx | | 03.07.2019 19:09
Drafted by Sven Petersen | Page 2 of 5 | Doc.-No.: 128-6-01-00

## Assembly

It is assumed, that the person, who assembles the Kernal Switch is experienced in soldering. First the SMD parts should be soldered, the bottom entry receptacle J1 should be soldered last. It can be aligned to the holes in the board using the pin header J5. Pin2 of J2 has to be clipped and the connector has to be inserted into the holes from the solder side. Then J1 has to be placed over those pins and the connector has to be aligned in a way, that it is centered on the J1 silk screen drawing and the SMD pins are in the middle of the solder pads. Then one pin has to be soldered. Then the connector might need to be corrected and a second pin can be soldered. If the pin header inserts easily from the bottom, all other pins can be soldered.

Finally, the through hole parts have to be soldered.

Cloe (or leave open) the solder bridge CP1, depending whether a short board (ASSY 250469, close CP1) or a long board (all other ASSY numbers, leave CP1 open) is present in the C64.

To prevent the components of the Kernal Switch from making contact with any parts of the C64 mainboards, the area top and bottom of the keyboard connectors can be taped with duct or gaffer tape.

After being completely assembled, the micro controller IC1 (ATmega238P) has to be programmed. Refer to document number 128-6-05-00 (Programming Guide).

For wiring the Kernal Adaptor, the Kernal Switch and the C64, refer to document number 128-6-04-00 (Wiring).

The Assembly of the Kernal Adaptor might require de-soldering the Kernal ROM U4 and installing a socket.

## Trouble shooting

In case the C64 does not start properly, make sure, that the Kernal Adaptor is inserted properly into the socket and the EPROM is properly programmed. At least the first Kernal has to be programmed. The Kernal Switch should sit firmly on the keyboard connector and do not make electrical contact with any component leads of the C64 mainboard.

The Atmega328P has to be programmed with either the production file or the *.hex and the fuses have to be set properly (refer to document 128-6-05-00: Programming Guide).

Also, it is important to open or close the configuration solder bridge CP1 on the module to determine between a short and a long board. Form short boards, the solder bridge has to be closed, the BASIC has to be in the first 8k of the EPROM and a Kernal (original recommended) has to be in the 2nd 8k of the EPROM.

In case the Kernals do not switch in the sequence as they were programmed into the EPROM, most likely, the wiring between the Kernal Switch and the Kernal Adapter is wrong (refer to document 128-6-04-00: Wiring)

In case it is not working at all, remove the cable between the Kernal Switch and the Kernal Adaptor and set jumpers. Set all three jumpers (A13, A14, A15) for a long board and the jumpers A14 and A15 for a short board. In case it is working now, the Kernal Switch is selecting the wrong Kernal (maybe an empty 8k slot). Again, check the cable, measure the pins A13, A14 and A15 on the J4 with a multimeter. Keep in mind, that the first Kernal for a short board is 001BIN and for a long board it is 000BIN. A 0 here is represented by a low voltage (<0.7V) and a 1 is represented by a HIGH voltage (>4V).

C64_KBCtrl_KSw_ModD_v0.docx | | 03.07.2019 19:09
Drafted by Sven Petersen | Page 3 of 5 | Doc.-No.: 128-6-01-00

If the problem is not solved, checking the solder joints is required. To see, if the software is running on the micro controller, a Serial Cable and a USB/Serial Adaptor plus the Arduino software (Tools → Serial Monitor, set to 9600 baud) might help.

After power up, the software should send messages via the serial cable. The RESTORE key has to be detected and reported (after holding it down) and a number key will be reported too.

Make sure, that the C64 power supply and the PC are connected and that the cables do not for a big loop. This might prevent a proper function. The serial connection is only for programming (in some cases) and for debugging, so it is not a problem, if a ground loop causes problems. It was experienced, that with a big ground loop (a couple of square meters) the C64 did not always start properly.

## Keyboard Monitoring

The columns 1-4 and 7 as well as the rows 0 and 3 are connected to IO-pins of the micro controller. The C64 sends a scan bit to the columns, which are HIGH on default. The scan bit is LOW and it is shifted through the columns, one at a time. The rows are read back by the C64. A LOW signal on one or more row bits indicates a pressed key.

The following keyboard scan information can be obtained by the microcontroller:

Column
7 | 4 | 3 | 2 | 1
Row 0 | “1” | “9” | “7” | “5” | “3”
Row 3 | “2” | “0” | “8” | “6” | “4”

It is obvious that only the numerals are being monitored. Further the RESTORE key is connected to the microcontroller.

## Programming model

Pin | GPIO | Arduino Function | Configuration
30 | PD0 | D0 | RxD | Input | Serial Receive
31 | PD1 | D1 | TxD | Output | Serial Transmit
32 | PD2 | D2 | Row0 | Input, weak pull-up | Active LOW, INT0
1 | PD3 | D3 | Row3 | Input, weak pull-up | Active LOW, INT1
2 | PD4 | D4 | KSW_A13 | Output | Kernal Switch A13
9 | PD5 | D5 | KSW_A14 | Output | Kernal Switch A14
10 | PD6 | D6 | KSW_A15 | Output | Kernal Switch A15
11 | PD7 | D7 | C64RES | Output | Active HIGH
23 | PC0 | A0 | COL1 | Input, weak pull-up | Keyboard column 1
24 | PC1 | A1 | COL2 | Input, weak pull-up | Keyboard column 2
25 | PC2 | A2 | COL3 | Input, weak pull-up | Keyboard column 3
26 | PC3 | A3 | COL4 | Input, weak pull-up | Keyboard column 4
27 | PC4 | A4 | COL7 | Input, weak pull-up | Keyboard column 7
28 | PC5 | A5 | RESTORE | Input, weak pull-up | RESTORE-Key, active LOW
12 | PB0 | D8 | SHORT_BRD | Input | Short Board, active LOW
13 | PB1 | D9 | RS1 | TBD | Reserve IO Pin#1
14 | PB2 | D10 | RS2 | TBD | Reserve IO Pin#2

C64_KBCtrl_KSw_ModD_v0.docx | | 03.07.2019 19:09
Drafted by Sven Petersen | Page 4 of 5 | Doc.-No.: 128-6-01-00

## Connectors

### J1 - Keyboard connector to mainboard

Bottom Entry receptacle (1x20p, pitch 2.54mm) – Harwin M20-7862042

Pin Signal | Pin Signal
1 | GND | 11 | ROW1 (PB1)
2 | No pin | 12 | ROW0 (PB0)
3 RESTORE | | 13 COL0 (PA0)
4 | +5V | 14 | COL6 (PA6)
5 | ROW3 (PB3) | 15 | COL5 (PA5)
6 | ROW6 (PB6) | 16 | COL4 (PA4)
7 | ROW5 (PB5) | 17 | COL3 (PA3)
8 | ROW4 (PB4) | 18 | COL2 (PA2)
9 | ROW7 (PB7) | 19 | COL1 (PA1)
10 | ROW2 (PB2) | 20 | COL7 (PA7)

### J2 – In System Programming

2x3 box pin header (2.54mm pitch). This connector is used for the initial in-system programming of the ATmega238p (IC1). 89

Pin Signal | Pin Signal
1 | MISO | 2 | +5V
3 | SCK | 4 | MOSI
5 | RESET (IC1) | 6 | GND

### J3 – Serial/Debug

1x5 pin header (2.54mm pitch). In Arduino mode (after programming the Arduino boot loader), a USB/serial converter can be used to transfer the compiled Arduino sketches and for debugging with the serial monitor.

Pin | Signal | USB/Serial converter
1 | GND | GND
2 | +5V | +5V
3 | TxD (output) | RX
4 | RxD (input) | TX
5 | DTR (input) | DTR

### J4 – IO-Connector

1x6 pin header (2.54mm pitch)

This connector outputs the control signals of this board. It is for being connected to the Kernal and/or keyboard adapter. It also provides two reserved IO-Pins for later use.

Pin | Signal | Function
1 | KSW_A13 | Kernal Switch/Adapter A13
2 | KSW_A14 | Kernal Switch/Adapter A14
3 | KSW_A15 | Kernal Switch/Adapter A15

C64_KBCtrl_KSw_ModD_v0.docx | | 03.07.2019 19:09
Drafted by Sven Petersen | Page 5 of 5 | Doc.-No.: 128-6-01-00
Pin | Signal | Function
4 C64_RESET | | RESET signal for the C64 (to be connected to a RESET point on the mainboard
5 | RESIO1 | Reserved IO
6 | RESIO2 | Reserved IO

### J5 - Keyboard connector

Pin header (1x20p, pitch 2.54mm) – Pin 2 clipped off (no pin)

Pin Signal | Pin Signal
1 | GND | 11 | ROW1
2 | No pin | 12 | ROW0
3 RESTORE | | 13 COL0
4 | +5V | 14 | COL6
5 | ROW3 | 15 | COL5
6 | ROW6 | 16 | COL4
7 | ROW5 | 17 | COL3
8 | ROW4 | 18 | COL2
9 | ROW7 | 19 | COL1
10 | ROW2 | 20 | COL7

## Documents

Document | Document Number
Disclaimer | -
Module Description (this document) | 128-6-01-**
Schematic | 128-1-01-**
PCB prints | 128-2-01-**
Functional Description | 128-6-02-**
Software Description | 128-6-03-**
Wiring | 128-6-04-**
Programming Guide | 128-6-05-**
Testing | 128-6-06-**
Bill of Material | 128-5-01-**.*
**: depends on revision.

## Revision History

### Rev. 0

- Prototype (fully functional)









C64_KBCtrl_KSw_FunD_v0.docx | | 03.07.2019 19:10
Drafted by Sven Petersen | Page 1 of 1 | Doc.-No.: 128-6-02-00

### C64 Keyboard Controlled Kernal Switch Rev. 0
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

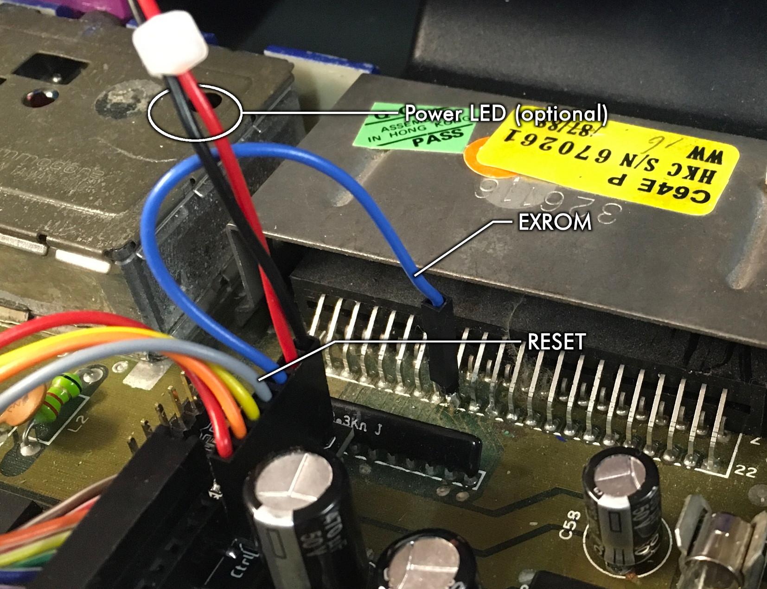
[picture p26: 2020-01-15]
Rev. 1/pictures/3481_-_EXROM_Pin_labeled.jpg

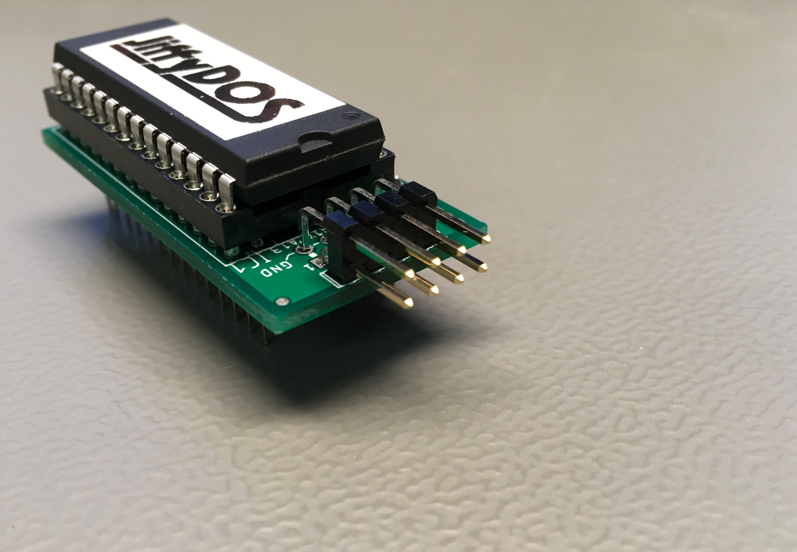
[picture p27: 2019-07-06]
Rev. 1/pictures/2202_-_Kernal_Adapter.JPG

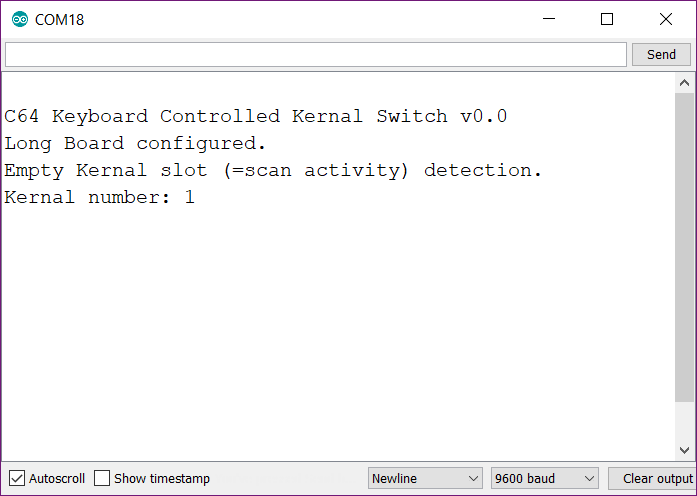
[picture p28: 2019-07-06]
Rev. 1/pictures/Serial_Monitor.png

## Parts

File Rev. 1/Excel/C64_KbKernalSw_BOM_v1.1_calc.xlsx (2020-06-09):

C64 Keyboard Controlled Kernal Switch Rev. 1
Bill of Material Rev. 1.1
Pos. | Qty | Value | €/ea | € | Comment
1 | 1 | 128-2-01-01 | 1.00 € | 1.00 € | 2 layer, Cu 35µ, HASL, 101.2mm x 20.0mm, 1.6mm FR4
2 | 0 | copper structure on pcb | 0.00 € | 0.00 € | no part, open Cutpad, close for ASSY250469
3 | 1 | 1x20 | 0.33 € | 0.33 € | pin header 1x20pin, 2.54mm pitch
4 | 1 | 1x7 | 0.16 € | 0.16 € | pin header 1x7pin, 2.54mm pitch
5 | 5 | 100n | 0.07 € | 0.35 € | SMD capacitor
6 | 4 | 10k | 0.02 € | 0.08 € | SMD resistor, 5% or better
7 | 1 | 1M | 0.02 € | 0.02 € | SMD resistor, 5% or better
8 | 2 | 1k | 0.02 € | 0.04 € | SMD resistor, 5% or better
9 | 2 | 22p | 0.02 € | 0.04 € | SMD capacitor
10 | 1 | ATMEGA328P-AU | 1.80 € | 1.80 € | Atmel/Micro Chip, e.g. Farnell 2443176
11 | 1 | BC846B | 0.08 € | 0.08 € | SMD transistor
12 | 1 | 16 MHz/20pF quarz | 0.63 € | 0.63 € | e.g. Fox Electronics, FOXSLF/160-20, Farnell 2063950
13 | 1 | LL4148 | 0.11 € | 0.11 € | SMD diode
14 | 1 | M20-7862042 | 0.99 € | 0.99 € | Harwin, e.g. Farnell 1256661
15 | 1 | WSL 6G | 0.19 € | 0.19 € | box pin header, 2x3pin, 2.54mm pitch
16 | 1 | 1x5 | 0.12 € | 0.12 € | pin header 1x5pin, 2.54mm pitch
17 | 1 | 220R | 0.02 € | 0.02 € | SMD resistor, 5% or better
18 | 1 | 330R | 0.02 € | 0.02 € | SMD resistor, 5% or better
19 | 0 | n/a | 0.00 € | 0.00 € | not placed
20 |  |  | Total | 5.98 €

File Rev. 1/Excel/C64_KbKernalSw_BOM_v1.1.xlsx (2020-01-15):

C64 Keyboard Controlled Kernal Switch Rev. 1
Bill of Material Rev. 1.1
Pos. | Qty | Value | Footprint | Ref.-No. | Comment
1 | 1 | 128-2-01-01 | 2 Layer | PCB Rev. 1 | 2 layer, Cu 35µ, HASL, 101.2mm x 20.0mm, 1.6mm FR4
2 |  | copper structure on pcb |  | CP1 | no part, open Cutpad, close for ASSY250469
3 | 1 | 1x20 | 1X20 | J5 | pin header 1x20pin, 2.54mm pitch
4 | 1 | 1x7 | 1X07 | J4 | pin header 1x7pin, 2.54mm pitch
5 | 5 | 100n | 0805 | C1, C2, C3, C6, C7 | SMD capacitor
6 | 4 | 10k | 0805 | R1, R2, R4, R5 | SMD resistor, 5% or better
7 | 1 | 1M | 0805 | R3 | SMD resistor, 5% or better
8 | 2 | 1k | 0805 | R6, R7 | SMD resistor, 5% or better
9 | 2 | 22p | 0805 | C4, C5 | SMD capacitor
10 | 1 | ATMEGA328P-AU | QFP80P900X900X120-32N | IC1 | Atmel/Micro Chip, e.g. Farnell 2443176
11 | 1 | BC846B | SOT23 | Q1 | SMD transistor
12 | 1 | 16 MHz/20pF quarz | HC49SLF | X1 | e.g. Fox Electronics, FOXSLF/160-20, Farnell 2063950
13 | 1 | LL4148 | SOD80C | D1 | SMD diode
14 | 1 | M20-7862042 | M20-7862042 | J1 | Harwin, e.g. Farnell 1256661
15 | 1 | WSL 6G | 2X03WV | J2 | box pin header, 2x3pin, 2.54mm pitch
16 | 1 | 1x5 | 1X05 | J3 | pin header 1x5pin, 2.54mm pitch
17 | 1 | 220R | 0805 | R8 | SMD resistor, 5% or better
18 | 1 | 330R | 0805 | R9 | SMD resistor, 5% or better
19 | 1 | n/a | 0805 | R10 | not placed
 |  | Rev. History
Pos. |  | Rev. 0 -> Rev. 1.1
1 |  | PCB revision
4 |  | Now 7 pin
17 |  | new
18 |  | new
19 |  | new

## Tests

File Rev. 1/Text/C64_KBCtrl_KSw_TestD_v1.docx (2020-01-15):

C64 Keyboard Controlled Kernal Switch Rev. 0

Prototype Testing

# Test Description

The test was executed with different models of the C64 mainboard.

- ASSY 250407 (Long Board)
- ASSY 250425 Rev. A (Long Board) in a Commodore 64C case
- ASSY 250469 Rev. 4 (Short Board)

The Kernal Adapter Rev. 0 (long board, short board) was selected to fit the C64 mainboard and the Kernal Switch was configured with the solder bridge CP1 accordingly.

All mainboards had a pin header (1 pin) installed to access their RESET-signal. The Kernal adapter and the Kernal switch were installed and wired.

The Kernal Adapter (Rev. 0) and the Kernal Switch (Rev. 0) was installed, a firm seat was checked for and the cable were made and installed.

The test was carried out with seven different Kernals:

Number | Kernal
1 | Original Commodore
2 | JiffyDOS (6.01)
3 | JaffyDOS (1.3)
4 | EXOS v3
5 | SpeedDOS
6 | DolphinDOS 2.0
7 | Turbo Tape v0.1
8 | No Kernal (long board only)

The EPROM of the short board version contained Commodore BASIC in the first 8k and the last 8k of the long board EPROM was left empty.

# Mechanical Fit

Installation ASSY 250469 Rev. 4: The Kernal Adaptor is not colliding with any other components, some had to be bend in one direction to give some space to the PCB. The Kernal Switch was above U18, no collision detected.

RP4 had to be bent backward, slightly. All other components were far enough away. The board was seating well, the contact of J1 was sufficient. No contact between the solder side through-hole pads and components of the C64 mainboard. It might be possible to get contact between those and the ground frame of ASSY 250469, when the module is not seated well.

It is recommended to apply electrical insulation tape to the solder side south of the keyboard connectors to prevent this.

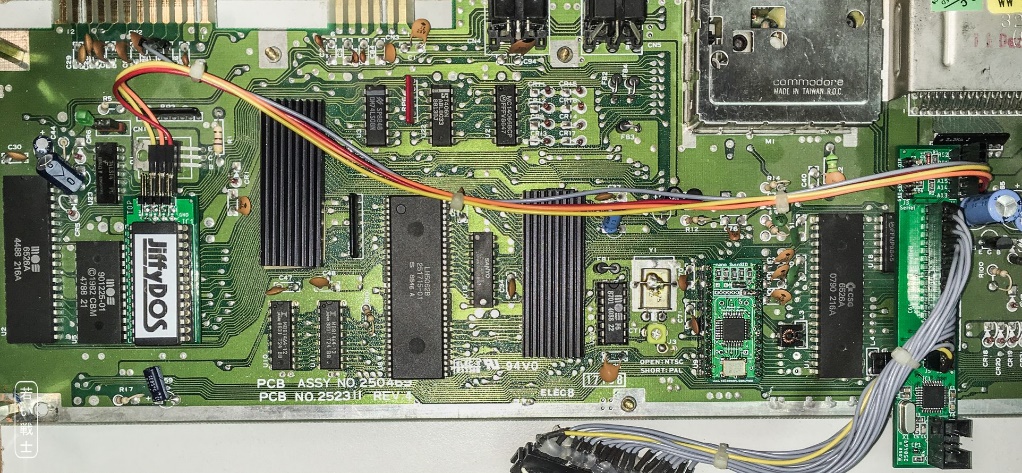
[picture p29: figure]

Figure 1: Installation ASSY250469

Installation ASSY 250425 Rev. A in C64C case:

The module fits on the board, it is seated properly, the contact of J1 is sufficient. The keyboard brackets do not collide with the PCB, the space is sufficient for the ICSP connector J2.

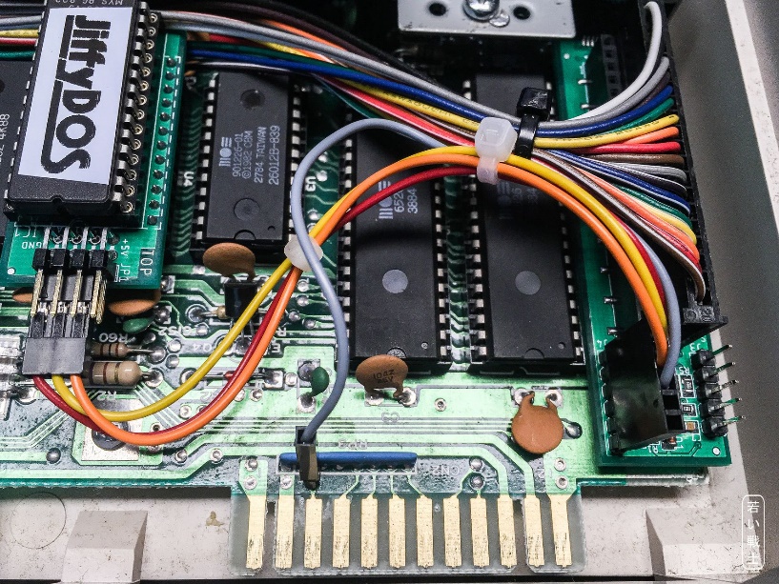
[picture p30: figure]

Figure 2: Installation ASSY250425

The protection diodes that are placed on top of other components on most ASSY250425 fit under the PCB. Since it is possible, that these diodes make contact with the through-hole pads of the module, it is required to apply electrical insulation tape the solder side of the board south of the keyboard connectors.

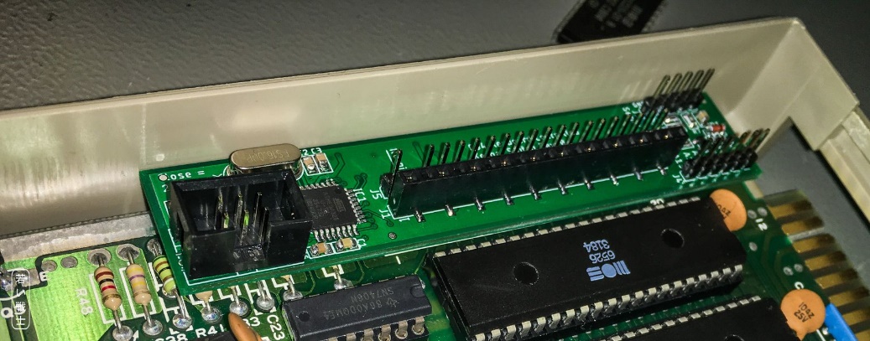
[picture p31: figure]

Figure 3: Installation ASSY250407 in bread bin case

Installation ASSY 250407 Rev. B in bread bin case:

The module fits on the board, it is seated properly, the contact of J1 is sufficient. The PCB does not collide with the components of the C64 south of the keyboard connector. It might be possible, that the pins of J2 scratch the resistors underneath it.

It is recommended to tape the solder side of the module south of the keyboard connector.

# Test of Functionality

## Long Board Version

The long board can switch between 8 Kernals. The EPROM was programmed with seven Kernals plus an empty 8th 8k EPROM slot.

### Holding the RESTORE key

Holding the RESTORE key for several seconds generated a RESET of the C64. This was reported on the serial interface. This test was carried out >20 times.

### Switching the Kernals

Pressing the number keys was detected properly and reported on the serial interface. Holding the RESTORE key and pressing a number key lead to changing the Kernal and resetting the C64. This worked like desired. The RESET pulse for the C64 was LOW for approximately 2 seconds.

All seven Kernals were tested several times each. No unwanted behavior was found.

### Power Cycle

Switching Kernals and at least 20 power cycles per Kernal were performed. The previously selected Kernal was executed after the power cycle. The value is properly stored in the (non-volatile) EEPROM of the microcontroller. No unwanted behavior was found.

### Switching to an Empty Kernal

After selecting a valid Kernal, it was pressed RESTORE 8 to switch to the empty Kernal. The result was a crash of the C64. One character on the screen is cycled quickly, nothing else was visible. After a timeout of several seconds, the module reported “no keyboard activity” on the serial interface, switched to Kernal 1 and reset the system. The C64 restarted with Kernal 1 (the original Kernal). The desired recovery procedure worked properly. The test was carried out several times, starting from each of the valid Kernals.

## Short Board Version

The short board can switch between 7 Kernals. The EPROM was programmed with BASIC and seven Kernals.

### Holding the RESTORE Key

Holding the RESTORE key for several seconds generated a RESET of the C64. This was reported on the serial interface. This test was carried out >20 times.

### Switching the Kernals

Pressing the number keys was detected properly and reported on the serial interface. Holding the RESTORE key and pressing a number key lead to changing the Kernal and resetting the C64. This worked like desired. The RESET pulse for the C64 was LOW for approximately 2 seconds.

All seven Kernals were tested several times each. No unwanted behavior was found.

### Power Cycle

Switching Kernals and at least 20 power cycles per Kernal were performed. The previously selected Kernal was executed after the power cycle. The value is properly stored in the (non-volatile) EEPROM of the microcontroller. No unwanted behavior was found.

# Test with Cartridges

The following cartridges were tested with the Kernal Switch:

- Final Cartridge 3+
- Power Cartridge
- Dela Dos
- Forth 64
- Diagnostic Rev. 586220
- 1541 Diagnostic/Test
- Ultimate II+
- Dead Test Rev. 781220

Except the Dead Test, all cartridges worked as desired, no unwanted behavior was found. Several power cycles were performed. The Diagnostic Rev. 586220 is configured as an EXROM cartridge, so at least initially, some keyboard scans are found.

The Dead Test cartridge does not perform keyboard scans. Thus, the Kernal Switch will reset the C64 after the time out of several seconds without keyboard scanning. This behavior was expected.

To provide non-interfered operation for this kind of cartridge, the module can be deactivated by pressing RESTORE 0 (zero). This was conducted: The Kernal was changed to Kernal 1. After switching off the C64, installing the Dead Test cartridge and powering up the computer again, the Dead Test was performed properly. The deactivation state was stored properly in the (non-volatile) EEPROM of the ATmega238P. Several tests cycles were performed. After unplugging the cartridge, the deactivation mode was switched off by selecting any of the Kernals. The state of activation was properly reported on serial interface. The desired behavior was shown.

# Conclusion

The Keyboard Controlled Kernal Switch is fully functional.

Note: Not all mainboard and case type combinations could be tested. Also, the used parts may vary. An assessment of a proper installation and suitable connector seat of the keyboard connector J5 and the bottom entry connector J1 should be performed with every installation.

Again, it is required to apply electrical insulation tape to the solder side in the area south of the keyboard connectors to prevent short circuit or scratching the parts underneath the module.

C64_KBCtrl_KSw_TestD_v0.docx 25.07.2019 18:51 Drafted by Sven Petersen Page 4 of 5 Doc.-No.: 128-6-06-01

C64_KBCtrl_KSw_TestD_v0.docx 25.07.2019 18:51 Drafted by Sven Petersen Page 1 of 1 Doc.-No.: 128-6-06-00

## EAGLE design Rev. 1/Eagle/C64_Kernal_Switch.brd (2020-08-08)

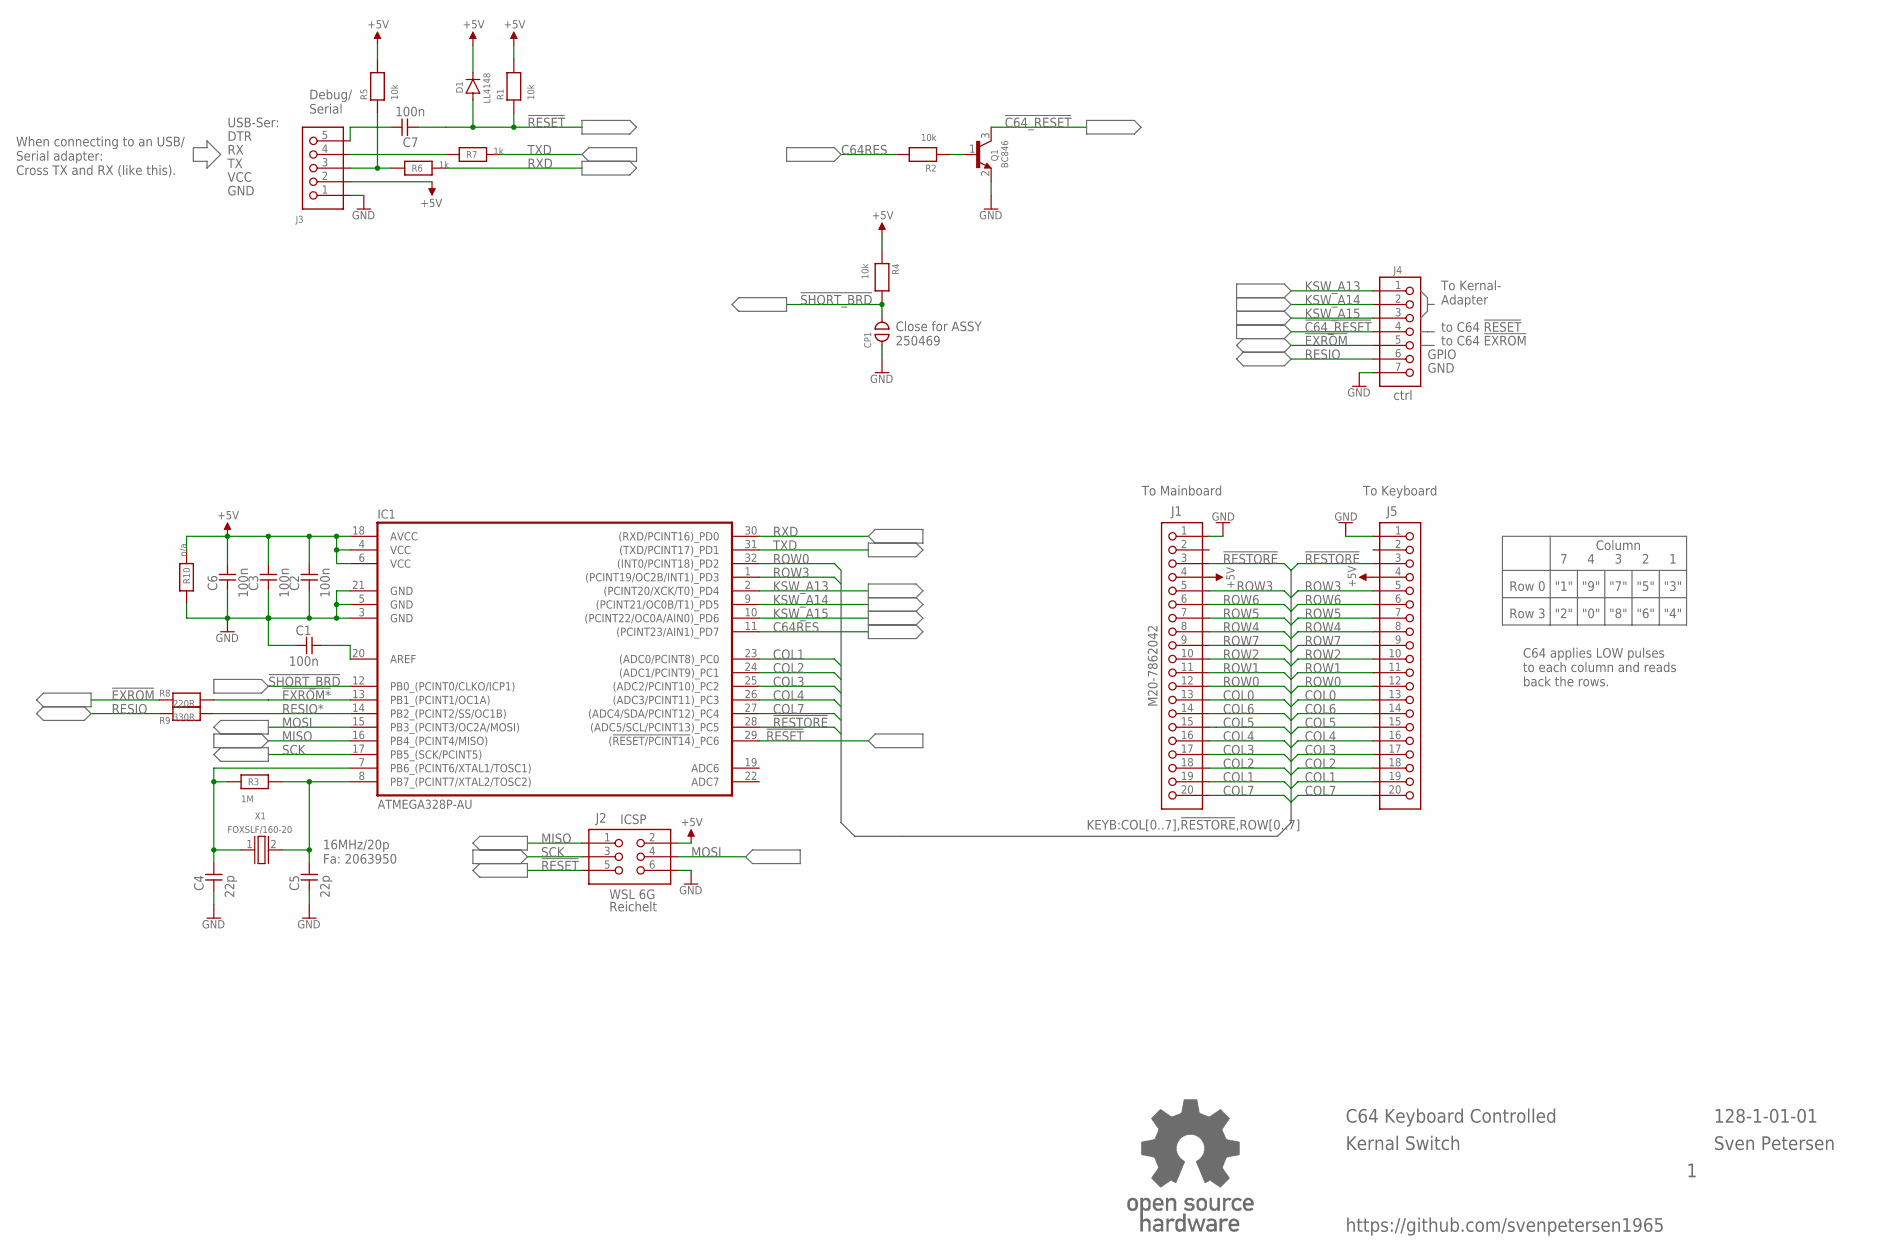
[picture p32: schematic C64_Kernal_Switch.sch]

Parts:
C1, C2, C3, C6, C7: 100n; 0805
C4, C5: 22p; 0805
CP1: OPEN; CP_OP
D1: LL4148; SOD80C
IC1: ATMEGA328P-AU; QFP80P900X900X120-32N
J1: M20-7862042; C64_KEYBOARD
J2: WSL 6G; 2X03WV
J3: n/a; 1X05
J4: PINHD-1X7; 1X07
J5: PINHD-1X20; 1X20
Q1: BC846; SOT23
R1, R2, R4, R5: 10k; 0805
R3: 1M; 0805
R6, R7: 1k; 0805
R8: 220R; 0805
R9: 330R; 0805
R10: n/a; 0805
U$55: OPEN_SOURCE_HW; OPENHW
X1: FOXSLF/160-20; HC49SLF

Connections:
!C64_RESET: J4.4, Q1.3 (C)
!EXROM: J4.5, R8.1
!EXROM*: IC1.13 (PB1_(PCINT1/OC1A)), R8.2
!RESET: C7.1, D1.A, IC1.29 ((!RESET/PCINT14!)_PC6), J2.5, R1.1
!RESTORE: IC1.28 ((ADC5/SCL/PCINT13)_PC5), J1.3, J5.3
!SHORT_BRD: CP1.2, IC1.12 (PB0_(PCINT0/CLKO/ICP1)), R4.2
+5V: C2.2, C3.2, C6.2, D1.K, IC1.4 (VCC), IC1.6 (VCC), IC1.18 (AVCC), J1.4, J2.2, J3.2, J5.4, R1.2, R4.1, R5.2, R10.2
C64RES: IC1.11 ((PCINT23/AIN1)_PD7), R2.2
COL0: J1.13, J5.13
COL1: IC1.23 ((ADC0/PCINT8)_PC0), J1.19, J5.19
COL2: IC1.24 ((ADC1/PCINT9)_PC1), J1.18, J5.18
COL3: IC1.25 ((ADC2/PCINT10)_PC2), J1.17, J5.17
COL4: IC1.26 ((ADC3/PCINT11)_PC3), J1.16, J5.16
COL5: J1.15, J5.15
COL6: J1.14, J5.14
COL7: IC1.27 ((ADC4/SDA/PCINT12)_PC4), J1.20, J5.20
GND: C1.1, C2.1, C3.1, C4.1, C5.1, C6.1, CP1.1, IC1.3 (GND), IC1.5 (GND), IC1.21 (GND), J1.1, J2.6, J3.1, J4.7, J5.1, Q1.2 (E), R10.1
KSW_A13: IC1.2 ((PCINT20/XCK/T0)_PD4), J4.1
KSW_A14: IC1.9 ((PCINT21/OC0B/T1)_PD5), J4.2
KSW_A15: IC1.10 ((PCINT22/OC0A/AIN0)_PD6), J4.3
MISO: IC1.16 (PB4_(PCINT4/MISO)), J2.1
MOSI: IC1.15 (PB3_(PCINT3/OC2A/MOSI)), J2.4
unnamed: C4.2, IC1.7 (PB6_(PCINT6/XTAL1/TOSC1)), R3.1, X1.1
unnamed: C5.2, IC1.8 (PB7_(PCINT7/XTAL2/TOSC2)), R3.2, X1.2
unnamed: C1.2, IC1.20 (AREF)
unnamed: Q1.1 (B), R2.1
unnamed: C7.2, J3.5
unnamed: J3.4, R7.1
unnamed: J3.3, R5.1, R6.1
RESIO: J4.6, R9.1
RESIO*: IC1.14 (PB2_(PCINT2/SS/OC1B)), R9.2
ROW0: IC1.32 ((INT0/PCINT18)_PD2), J1.12, J5.12
ROW1: J1.11, J5.11
ROW2: J1.10, J5.10
ROW3: IC1.1 ((PCINT19/OC2B/INT1)_PD3), J1.5, J5.5
ROW4: J1.8, J5.8
ROW5: J1.7, J5.7
ROW6: J1.6, J5.6
ROW7: J1.9, J5.9
RXD: IC1.30 ((RXD/PCINT16)_PD0), R6.2
SCK: IC1.17 (PB5_(SCK/PCINT5)), J2.3
TXD: IC1.31 ((TXD/PCINT17)_PD1), R7.2

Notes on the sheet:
C64 Keyboard Controlled
128-1-01-01
Sven Petersen
ICSP
Reichelt
16MHz/20p Fa: 2063950
USB-Ser:
DTR
VCC
GND
Debug/ Serial
Column
Row 0
Row 3
"3"
"5"
"7"
"9"
"1"
"2"
"0"
"8"
"6"
"4"
To Kernal- Adapter
to C64 !RESET
To Mainboard
To Keyboard
Close for ASSY 250469
C64 applies LOW pulses to each column and reads back the rows.
GPIO
Kernal Switch
to C64 !EXROM
ctrl
When connecting to an USB/ Serial adapter: Cross TX and RX (like this).
https://github.com/svenpetersen1965

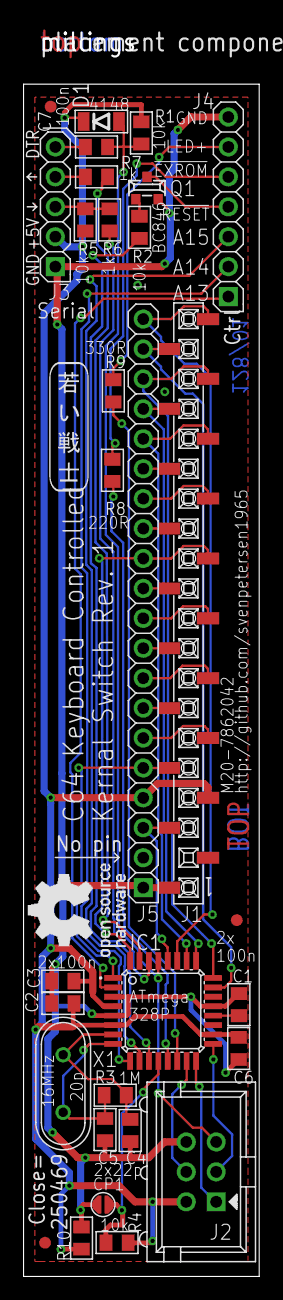
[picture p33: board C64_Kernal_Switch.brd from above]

Board: 2 copper layers, 20.0 x 101.2 mm, 34 parts (0 on the bottom side), 42 nets.

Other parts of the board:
U$44: 2LAYER
U$45, U$46, U$47: SMD_REF_R1MM
U$52: PCB-TITLE/
U$54: SVEN_TAG

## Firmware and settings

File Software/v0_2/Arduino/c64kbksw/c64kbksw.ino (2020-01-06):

/*  Software for the keyboard controlled kernal switch
 *  by Sven Petersen, 2020
 *  
 *  Revisioon history 
 *  Rev. 0.0: initial release
 *  Rev. 0.1: since some games (e.g. Gyruss) modify the reset procedure, the "unstoppable reset" (= EXROM Reset) was 
 *            implemented. Pressing RESTORE for approximatety 2-4 seconds is a normal reset, holding it longer =  
 *            EXROM reset.
 *  Rev. 0.2: Implemented signalling on RESIO2.          
 */

#define LED
//#define buzzer

#include <EEPROM.h>

/* Configuration */
const bool recover_empty = true;     //enable recover to Kernal one, in case an empty/not working kernal was selected
const int  NumKernal = 8;            //This is the highest valid Kernal number
 
/* pin definitions */
const int row0 = 2;         // Row signal, input, active low, INT0
const int row3 = 3;         // Row signal, input, active low, INT1
const int KSW_A13 = 4;      // output, A13 to kernal adaptor/switch
const int KSW_A14 = 5;      // output, A14 to kernal adaptor/switch
const int KSW_A15 = 6;      // output, A15 to kernal adaptor/switch
const int C64RESET = 7;     // output, RESET signal for the C64
const int col1 = A0;        // input, column signal, active low
const int col2 = A1;        // input, column signal, active low
const int col3 = A2;        // input, column signal, active low
const int col4 = A3;        // input, column signal, active low
const int col7 = A4;        // input, column signal, active low
const int nRESTORE = A5;    // input, RESTORE key, active low
const int nSHORT_BRD = 8;   // input, short board jumper
const int nEXROM = 9;       // /EXROM Pin connected to pin header J4, pin 5 
// const int RSVD  = 10;    // reserved. Pin connected to pin header J4, pin 6
const int Signalling  = 10; // Pin for signaling (LED or buzzer with tone generator), pin header J4, pin 6

#ifdef buzzer
const bool sig_idle = LOW;   // idle level of J4, pin 6 (should be HIGH for a power LED) 
#else
const bool sig_idle = HIGH;  // idle level of J4, pin 6 (should be HIGH for a power LED)
#endif 

const int Restore_Count = 1500; // count appr. 2 seconds for RestoreKey before Reset
const int EXROM_Count = 3000;   // limit for EXROM reset
const int Sig_time = 500; // constant for signalling duration

/* other constants */
#define EEPROMAddr 0        // EEPROM Address of last kernal selection
#define ScanDelay 10000     // delay ibn ms before reset for no scan activity or an empty kernal memory slot, respectively

/* variables */
byte KOffset = 0;           // offset for kernal number
byte KNumber = 0;           // Kernal number
byte KAddr = 0;             // Address bits for Kernal
bool RestoreKey = 0;        // holds the info, if the restore key is pressed 
bool oldRestoreKey = 0;     // remeber the old status to compare
int  countup = 0;           // counter for restore key time measurement
byte key = 128;             // calculate the Key
int  KMax;                  // holds the highest Kernal Number


/* Data Exchange variables for ISR (have to be volatile) */
volatile bool NumPressed = 0;  // ISR flag for number pressed
volatile bool NumOdd = 0;      // ISR flag for odd numbers. Row0 => odd numbers, Row3 => even numbers
volatile byte ColData = 0x1F;  // column data, read from PORTD

/* in case, the kernal switch switches to a memory slot without a proper kernal software
 *  there is no keyboard scan activity. That is why the kernal switch cannot detect keys anymore
 *  to circumvent this, the column scan activity is detected. If there is no activity after switching kernals
 *  the kernal is set to #1 and the C64 is reset.
 */
byte columns;           // variable for reading out the column
int scan_cnt;           // 5000 miliseconds without scan changing to kernal #1 and resetting
int scan_found;         // flag for keybioard activity detected
byte inactive = 0;      // keyboard scan inactive: 1 -> inactive, 0 = active
bool exrom_mode = 0;    // exrom reset: 0 => no, 1 => yes
int signalling_cnt = 0; // count down for signalling pin

void setup() {
  /* keyboard scan signals */
  pinMode( row0, INPUT_PULLUP);  // pullup required for MOS logic
  pinMode( row3, INPUT_PULLUP);  // pullup required for MOS logic
  pinMode( col1, INPUT_PULLUP);  // pullup required for MOS logic
  pinMode( col2, INPUT_PULLUP);  // pullup required for MOS logic
  pinMode( col3, INPUT_PULLUP);  // pullup required for MOS logic
  pinMode( col4, INPUT_PULLUP);  // pullup required for MOS logic
  pinMode( col7, INPUT_PULLUP);  // pullup required for MOS logic
  pinMode( nRESTORE, INPUT_PULLUP);  // pullup required for MOS logic
  pinMode( nEXROM, INPUT );      // it needs to be high impedance, will switch to LOW and OUTPUT when required.
  digitalWrite( nEXROM, HIGH );
  digitalWrite( Signalling, sig_idle ); // Signalling pin6, J4
  pinMode( Signalling, OUTPUT);

  /* jumper */
  pinMode(nSHORT_BRD, INPUT);   // jumper: LOW = Short Board => lowest kernal number is 1
  if (digitalRead(nSHORT_BRD) == LOW)
  { 
    KOffset = 1; // it is a short board! kernal number offset is 1, since the BASIC is in the lowest 8k of the Kernal ROM
  }

  /* last kernal from eeprom */
  KNumber = EEPROM.read(EEPROMAddr);
  if ((KNumber < 1) || (KNumber > 8-KOffset)) { // if out of range, the first kernal is selected.
    KNumber = 1;
    EEPROM.write(EEPROMAddr, KNumber);
  }
  inactive = EEPROM.read(EEPROMAddr+1);         // keyscan inactive flag
  if (inactive > 1) {
    inactive = 0;
    EEPROM.write(EEPROMAddr+1, inactive);
  }
  exrom_mode = 0;                               // initialize exrom mode (for reset). 0 = no exrom reset
  
  KAddr = KNumber - 1 + KOffset; // Calculate the address bits.
  // For long boards, it should be between 0 and 7,
  // for short boards, it should be 1 to 7, because the first 8k are occupied by the BASIC ROM. 
  
  /* Control outputs (for Kernal Adaptor and C64) */
  SetAddressBits( KAddr );        // set the MS address bits for the kernal ROM
  pinMode( KSW_A13, OUTPUT );     // make it an output   
  pinMode( KSW_A14, OUTPUT );     // make it an output
  pinMode( KSW_A15, OUTPUT );     // make it an output
  digitalWrite( C64RESET, LOW );  // no reset for the C64
  pinMode( C64RESET, OUTPUT );    // make it an output

  if (recover_empty == true) {
    scan_cnt = ScanDelay;         // reset scan countdown
    scan_found = false;           // reset detection flag 
    KMax = 8 - KOffset; 
  }
  else {
    scan_cnt = 0;                 // reset scan countdown
    scan_found = true;            // reset detection flag
    KMax = NumKernal;
  }
  if (inactive == 1) {             // if scan timeout is inactive, just set scan_found
    scan_found = true;
    scan_cnt = 0;
  }
      
  attachInterrupt(digitalPinToInterrupt(row0), ISR_row0, LOW); 
  attachInterrupt(digitalPinToInterrupt(row3), ISR_row3, LOW);
  
  Serial.begin(9600);  // start serial interface
  /* output status etc. */
  Serial.println( "\nC64 Keyboard Controlled Kernal Switch v0.20" );
  if (KOffset == 1) {
    Serial.println("Short Board configured.");
  }
  else {
    Serial.println("Long Board configured.");
  }
  if (recover_empty == true) {
    Serial.print("Empty Kernal slot (=scan activity) detection: ");
    if (inactive == 1 ) {
      Serial.println("inactive.");
    }
    else {
      Serial.println("active.");
    }
  }
  else {
    Serial.print("Number of Kernals: ");
    Serial.println(NumKernal);
  }
  Serial.print("Kernal number: ");
  Serial.println( KNumber );
}

/* This function sets the address bits on the pin header J4. Parameter is addr (0..7) */
void SetAddressBits( byte addr ) {
   digitalWrite( C64RESET, HIGH );                              // do it, while /reset is low (samle like the port pin is high)
   delay (50 );                                                 // wait 50 ms
   if ((addr & 1) == 0) {         // A13                  
    digitalWrite(KSW_A13, LOW);
  }
  else {
    digitalWrite(KSW_A13, HIGH);  
  }
  if ((addr & 2) == 0) {          // A14
    digitalWrite(KSW_A14, LOW);
  }
  else {
    digitalWrite(KSW_A14, HIGH);  
  }
  if ((addr & 4) == 0) {          // A15
    digitalWrite(KSW_A15, LOW);
  }
  else {
    digitalWrite(KSW_A15, HIGH);  
  }
}

void ResetC64() {
  digitalWrite( Signalling, !sig_idle );                     // Signalling active
  digitalWrite( C64RESET, HIGH );                            // issue a reset pulse for the C64
  delay( 100 );                                              // 100ms delay
  if (exrom_mode == 1) {
    digitalWrite( nEXROM, LOW );                             // exrom pin low
    pinMode( nEXROM, OUTPUT );                               // and output
  }
  delay( 300 );                                              // pulse duration: 100+300ms
  digitalWrite( C64RESET, LOW );
  if (exrom_mode == 1) {
    delay( 300 );                                            // EXROM should be 300ms longer LOW than RESET
    pinMode( nEXROM, INPUT );                                // and input = high impedance (HIZ)
    digitalWrite( nEXROM, HIGH );                            // exrom pin high
  }
  if ((recover_empty == true) && (inactive == 0)) {
    scan_cnt = ScanDelay;                                    // reset scan countdown
    scan_found = false;                                      // reset detection flag
  }  
  else {
    scan_cnt = 0;
    scan_found = true;
  }
  countup = 0;
  digitalWrite( Signalling, sig_idle );                      // Signalling inactive
}

void SwitchKernal() {
  digitalWrite( C64RESET, HIGH );                            // issue a reset pulse for the C64
  SetAddressBits( KAddr );                                   // set the address bits A15..A13
  Serial.print("Change to Kernal number: ");                 // send the status to serial
  Serial.println( KNumber );
  ResetC64();                                                // Reset the C64
  delay( 2000 );                                             // give some delay to release the RESTORE key
}

// Interrupt Service Routine for Row0
void ISR_row0() {
  if (NumPressed == 0) {                  // only process info, after the flag was reset by main routine
     ColData = PINC & 0x1F;               // read the columns
     scan_found = true;                   // any activity here indicates a working kernal
     NumOdd = 1;                          // row0 has the odd numbers
     if ((ColData != 0x1F) && (ColData !=0)) {               // only set the flag, when a number is pressed 
       NumPressed = 1;
     }  
  }
}

// Interrupt Service Routine for Row3
void ISR_row3 () {
  if (NumPressed == 0) {                  // only process info, after the flag was reset by main routine
     ColData = PINC & 0x1F;               // read the columns
     scan_found = true;                   // any activity here indicates a working kernal
     NumOdd = 0;                          // row3 has the even numbers
     if ((ColData != 0x1F) && (ColData !=0)) { // only set the flag, when a number is pressed 
       NumPressed = 1;
     }  
  }
}

void loop() {
  /* find the scan activity to make sure, the selected Kernal is working */
  if (scan_found == false) {                            // if not yet a scan activity is detected
    columns = PINC & 0x1F;                              // read the column data
    if ((columns != 0x1F)) {                            // activity found?
      scan_found = true;                                // set flag
      Serial.println( "Keyboard scan detected."); 
    }
    else {
      if (scan_cnt > 0) {                               // if the count down is not elapsed
        scan_cnt--;                                     // then decrement
        delayMicroseconds( 33 );
      }
      else {
        Serial.println( "No keyboard scan detected.");  // the count down is elapsed!
        KNumber = 1;                                    // Set Kernal Number 1 (it is assumed, that this is not empty)
        EEPROM.write(EEPROMAddr, KNumber);              // and save in EEPROM
        KAddr = KOffset;                                // Calculate the address bits.
        SwitchKernal();                                 // Switch Kernal Number and reset C64
      }
    }
  }
  
  /* process restore key */ 
  if (digitalRead( nRESTORE ) == HIGH) {
     if (RestoreKey == 1) {                // now no RESTORE, but last status was RESTORE => Restore key released 
        if (countup > EXROM_Count) {       // is the limit for EXROM reset reached?
          exrom_mode = 1;
          Serial.print( "EXROM mode: ");
        }
        if (countup > Restore_Count) {
          Serial.println("Restore key => Reseting the C64");
          ResetC64();                      // RESET the C64
          exrom_mode = 0;
        }
     }
     RestoreKey = 0;                      // in case the reading is HIGH, the Restore key is not pressed
     countup = 0;                         // restart the count down
  }
  else {
    RestoreKey = 1;                       // in case the restore is pressed, count up
    countup++;
    if (countup == Restore_Count ) {
       digitalWrite( Signalling, !sig_idle );
       signalling_cnt = Sig_time;
    }
    if (countup > EXROM_Count) {          // time limit for EXROM reached?
       exrom_mode = 1;                    // activate EXROM mode
       Serial.println("EXROM mode: Restore key => Reseting the C64");
       ResetC64();                        // reset the C64
       RestoreKey = 0;                    // restart the restore key
       countup = 0;                       // restart the count down
       exrom_mode = 0;                    // reset EXROM mode
    }
  }
  if (signalling_cnt > 0) {
    if (--signalling_cnt == 0) {
      digitalWrite( Signalling, sig_idle );
    }
  }
  /* The ISR will set NumPressed to 1, in case some number key is pressed 
     In case something is found, the column data, which was read by the ISR 
     is being processed here.  
  */
  if (NumPressed == 1) {                     // if a number key is pressed: process the data
    if ((ColData & B00010000) == 0) {        // column 7: "1"
      key = 1;
    }
    else if ((ColData & B00000001) == 0) {   // column 1: "3"
      key = 3;
    }
    else if ((ColData & B00000010) == 0) {   // column 2: "5"
      key = 5;
    }
    else if ((ColData & B00000100) == 0) {   // column 3: "7"
      key = 7;
    }
    else if ((ColData & B00001000) == 0) {   // column 4: "9"
      key = 9;
    }
    /*
     * The even numbers are on row 3, the odd numbers are on row 1
     * NumOdd is set by the ISR
    */
    if (NumOdd == 0) {                       // the even number are higher by one
      key++;
    }
    if (key == 10) {                         // in case it is a "0" 
      key = 0;
    }
    Serial.print("Key ");
    Serial.print(key);
    Serial.println(" detected.");
    if ((key > 0) && (key < KMax+1) && (RestoreKey == 1)) {       // restore pressed and key in range
       KNumber = key;                                             // set Kernal Number
       EEPROM.write(EEPROMAddr, KNumber);                         // write it to the EEPROM
       KAddr = KNumber - 1 + KOffset;                             // Calculate the address bits. 
                                                                  // For long boards, it should be between 0 and 7,
                                                                  // for short boards, it should be 1 to 7, because the first 8k are occupied by the BASIC ROM. 
       inactive = 0;                                              // every valid kernal leaves inactive state
       EEPROM.write(EEPROMAddr+1, inactive);                      // write it to EEPROM
       SwitchKernal();                                            // Switch Kernal Number and reset C64
    }
    else if ((key == 0) && (RestoreKey == 1)) {                   // key "0" switches to kernal #1 and enters inactive state
      KNumber = 1;                                                // inactove means, that the initial key scan timeout is inactive
      EEPROM.write(EEPROMAddr, KNumber);                          // which is useful for catridges, that do not perform a keyboard scan
      KAddr = KNumber - 1 + KOffset;
      inactive = 1;                                               // enter inactive state
      EEPROM.write(EEPROMAddr+1, inactive);                       // write it to EEPROM
      Serial.println( "Kernal 1 and scan timeout inactive." );    // send to serial
      SwitchKernal();                                             // Switch Kernal Number and reset C64
    }
    else {
      key = 128;                                                  // reset the key number
    }
    NumPressed = 0;                                               // reset the flag, so the ISR can process key matrix again
  }
  else {
    key = 128;                                                    // reset the key number
  }
  delayMicroseconds( 1000 );                                      // delay 1ms per loop (not calibrated)
}

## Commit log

2019-07-05 Initial upload
    [C64_KbKernalSw_BOM_v0.0.xlsx, C64_Kernal_Switch.brd, C64_Kernal_Switch.sch]
2019-07-25 Revision 1
    Documentation is preliminary. The hardware is untested.
    [C64_KbKernalSw_BOM_v1.0.xlsx, C64_Kernal_Switch.brd, C64_Kernal_Switch.sch]
2020-01-06 Firmware release v0.2
    Firmware v0.2 uses the remaining GPIO on J4 for signalliting the reset on a power LED. This is normally on. When pressing RESTORE for about 3 seconds, the LED will switch off for a short time, indicating that a normal reset will be performed when RESTORE is released. Holding RESTORE for about 5 seconds will initiate an EXROM reset. While the reset, the LED will be off for a short time, too.
    [c64kbksw.ino]
2020-01-15 Rev. 1 Documentation released
    The final documentation is released
    [C64_KbKernalSw_BOM_v1.1.xlsx, C64_Kernal_Switch.brd, C64_Kernal_Switch.sch]
2020-06-09 Calculation of the copmponent prices added
    [C64_KbKernalSw_BOM_v1.1_calc.xlsx]
2020-08-08 Silk Screen Update
    [C64_Kernal_Switch.brd, C64_Kernal_Switch.sch]
